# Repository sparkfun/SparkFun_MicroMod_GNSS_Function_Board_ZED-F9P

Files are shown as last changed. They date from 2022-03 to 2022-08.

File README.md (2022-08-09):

SparkFun MicroMod GNSS Function Board - ZED-F9P
========================================

SparkFun MicroMod GNSS Function Board - ZED-F9P (https://www.sparkfun.com/products/19663)

[*SparkFun MicroMod GNSS Function Board - ZED-F9P (GPS-19663)*](https://www.sparkfun.com/products/19663)

The SparkFun MicroMod GNSS Function Board - ZED-F9P provides high precision GNSS capabilities for MicroMod projects using Main Board/Function Board assemblies. The ZED-F9P module from u-blox is capable of up to 10mm 3-dimensional accuracy though the module requires a clear view of the sky as well as correction data from an RTCM source to achieve this level of precision. The ZED-F9P can act as a base station as well so you can use it with a second Function Board (or another SparkFun ZED-F9P product) together to achieve millimeter positional accuracy.

Repository Contents
-------------------

* **/Documentation** - Data sheets, additional product information
* **/Firmware** - Example code 
* **/Hardware** - Eagle design files (.brd, .sch)
* **/Libraries** - Libraries for use with the <PRODUCT NAME>
* **/Production** - Production panel files (.brd)
* **/Software** - Related software for the <PRODUCT NAME>

Documentation
--------------
* **[SparkFun u-blox GNSS Arduino Library](https://github.com/sparkfun/SparkFun_u-blox_GNSS_Arduino_Library)** - u-blox GNSS Arduino library for SparkFun u-blox products.
* **[Hookup Guide](https://learn.sparkfun.com/tutorials/micromod-gnss-function-board---zed-f9p-hookup-guide)** - Basic hookup guide for the MicroMod GNSS Function Board - ZED-F9P.

Product Versions
----------------
* [GPS-19663](https://www.sparkfun.com/products/19663)- MicroMod GNSS Function Board - ZED-F9P Initial Release

Issues
------------
See the [issue template](.github/ISSUE_TEMPLATE/) folder for more information on how to raise issues for bugs and new features.

License Information
-------------------

This product is _**open source**_! 

Please review the LICENSE.md file for license information. 

If you have any questions or concerns on licensing, please contact technical support on our [SparkFun forums](https://forum.sparkfun.com/viewforum.php?f=152).

Distributed as-is; no warranty is given.

- Your friends at SparkFun.

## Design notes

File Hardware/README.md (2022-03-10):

SparkFun <PRODUCT NAME> Design Files
=====================================

The .sch and .brd files hare are Eagle CAD schematic and PCB design files from SparkFun Electronics.
A freeware version of Autodesk Eagle can be found [here](https://www.autodesk.com/products/eagle/free-download).

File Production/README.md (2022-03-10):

SparkFun <PRODUCT NAME> Production Files
=========================================

These are the production files SparkFun uses for printing PCBs.

License Information
-------------------
This product is open source! 

The hardware is released under [Creative Commons ShareAlike 4.0 International](https://creativecommons.org/licenses/by-sa/4.0/).

Please use, reuse, and modify these files as you see fit. Please maintain attribution to SparkFun Electronics and release anything derivative under the same license.

Distributed as-is; no warranty is given.

- Your friends at SparkFun.

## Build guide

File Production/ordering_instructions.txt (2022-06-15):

panel size, 128x137mm
PCB thickness, 0.8mm
number of layers, 4
bevel, Gold Fingers + 45° Finger Chamfered
soldermask color, Red
silkscreen color, White
oz copper, 1oz
finish, ENIG
stencils, none
pcs per panel, 6
min trace width, 0.1100mm / 0.0043in
min drill size, 0.3000mm / 0.0118in
filename to layer stackup 1/2/3/4: GTL, GL2, GL3, GBL

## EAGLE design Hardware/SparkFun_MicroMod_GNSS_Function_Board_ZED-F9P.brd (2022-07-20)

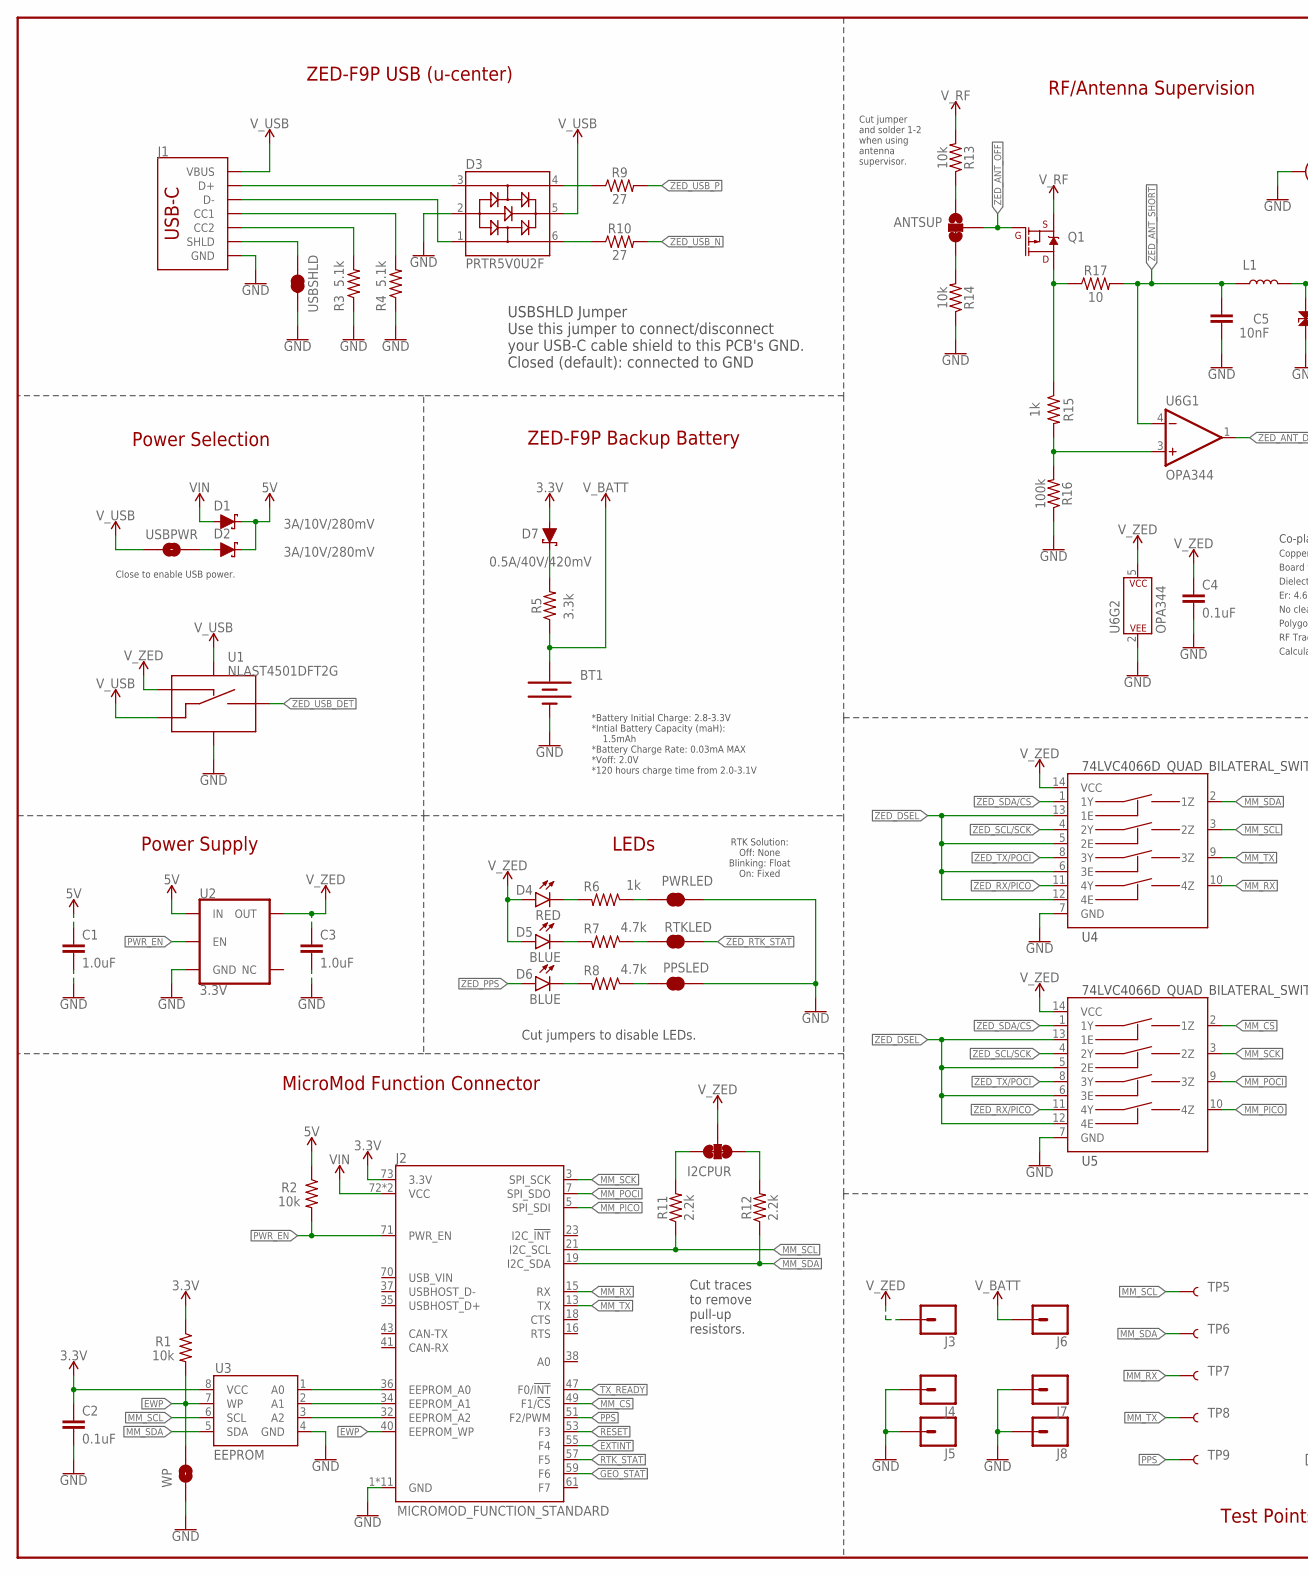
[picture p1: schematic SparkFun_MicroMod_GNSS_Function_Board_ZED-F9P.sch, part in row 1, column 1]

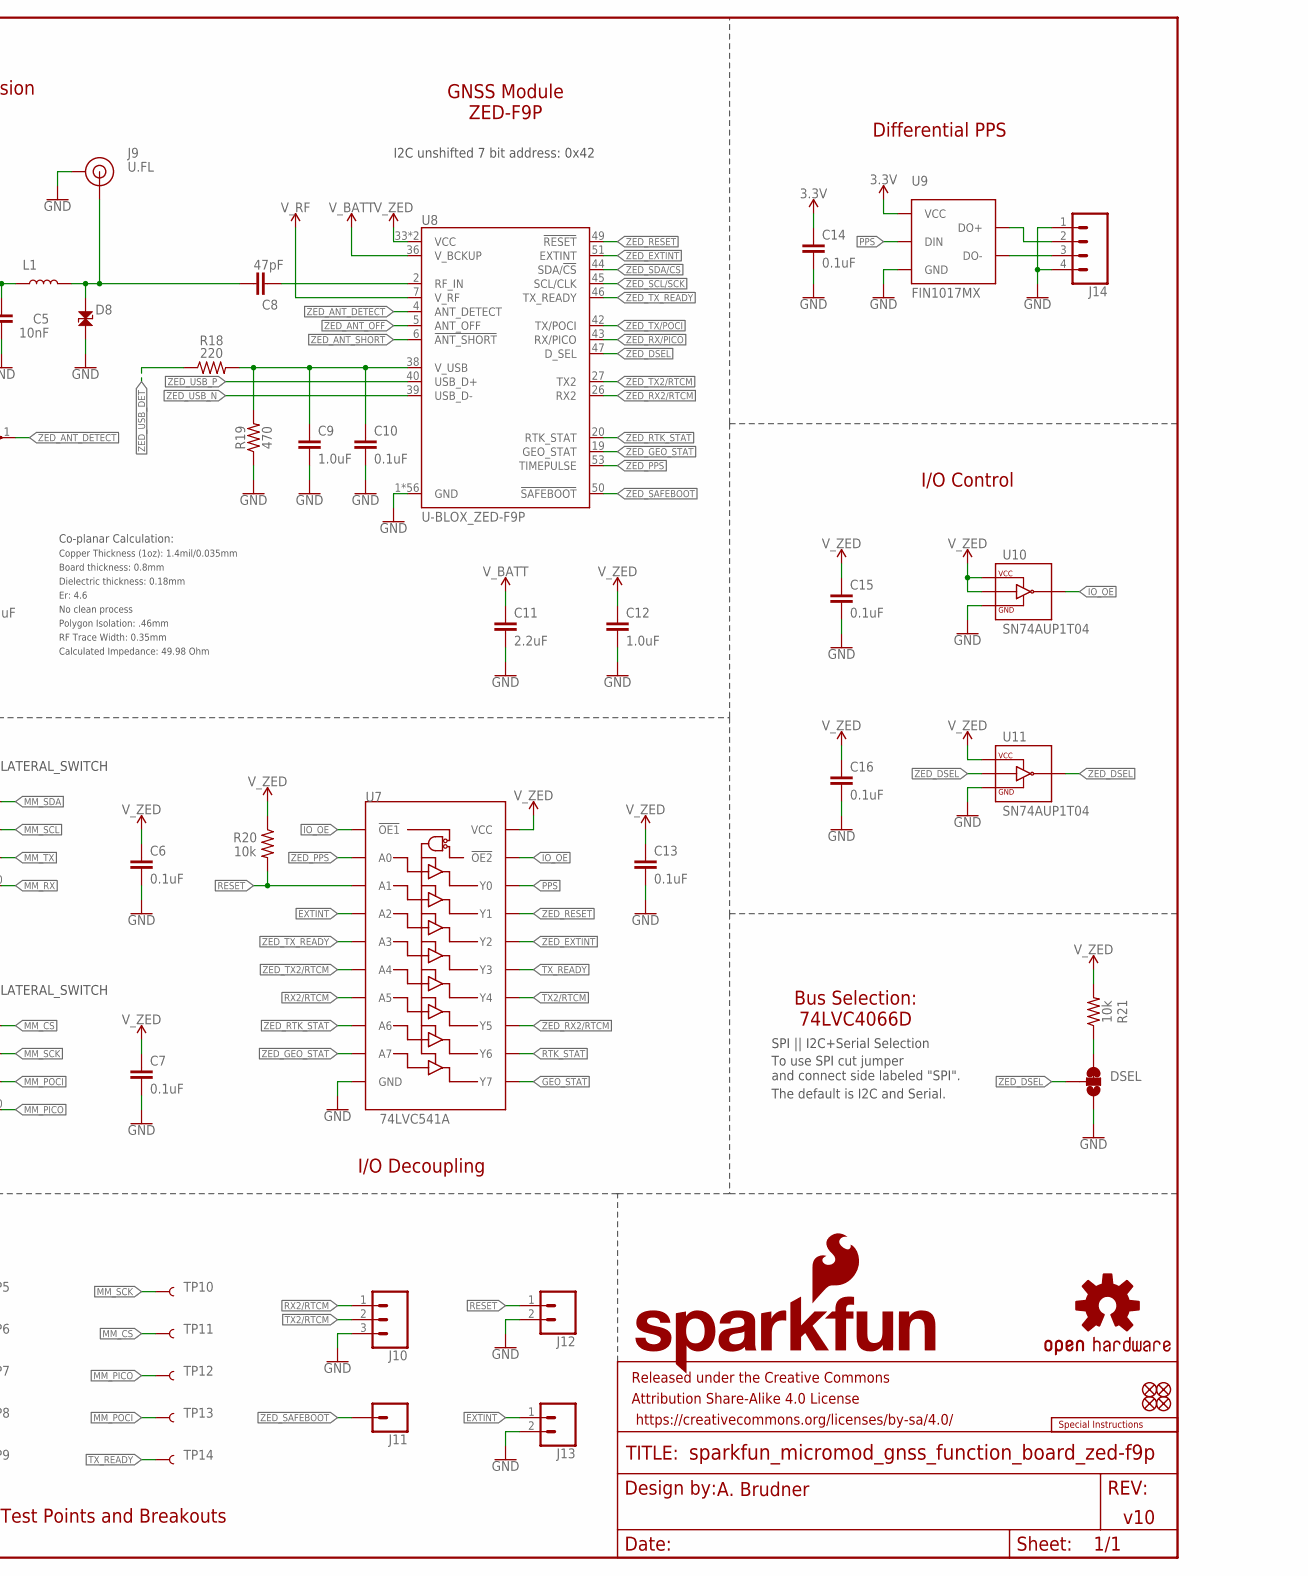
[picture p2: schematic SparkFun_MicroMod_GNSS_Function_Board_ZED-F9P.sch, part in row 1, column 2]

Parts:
ANTSUP: JUMPER-SMT_3_1-NC_TRACE_SILK; SMT-JUMPER_3_1-NC_TRACE_SILK
BT1: RELOWABLE_BATTERY_MS421R; MS421R_IV03E
C1, C3, C9, C12: 1.0uF; 0402-TIGHT
C2, C4, C6, C7, C10, C13, C14, C15, C16: 0.1uF; 0402-TIGHT
C5: 10nF; 0402-TIGHT
C8: 47pF; 0402-TIGHT
C11: 2.2uF; 0402-TIGHT
D1, D2: 3A/10V/280mV; SOD-323
D3: PRTR5V0U2F; SOT886
D4: RED; LED-0603
D5, D6: BLUE; LED-0603
D7: 0.5A/40V/420mV; SOD-323
D8: PESD0402-0402T; 0402-TIGHT
DSEL: JUMPER-SMT_3_1-NC_TRACE_SILK; SMT-JUMPER_3_1-NC_TRACE_SILK
FD1, FD2, FD3, FD4: FIDUCIALUFIDUCIAL; FIDUCIAL-MICRO
FRAME1: FRAME-LEDGER; CREATIVE_COMMONS
I2CPUR: JUMPER-SMT_3_2-NC_TRACE_SILK; SMT-JUMPER_3_2-NC_TRACE_SILK
J1: USB Female Type C Connector; USB-C-16P-4LAYER-ISOLATED
J2: MICROMOD_FUNCTION_STANDARD; M.2-CARD-E-22_FUNCTION_STANDARD
J3, J4, J5, J7, J8, J11: CONN_01PTH_NO_SILK_YES_STOP; 1X01_NO_SILK
J6: CONN_01PTH_NO_SILK_SMALL; 1X01_SMALL
J9: U.FL
J10: 455-1750-1-ND; 1X03_NO_SILK
J12, J13: CONN_021X02_NO_SILK; 1X02_NO_SILK
J14: CONN_041X04_NO_SILK; 1X04_NO_SILK
L1: 150nH; 0402_MURATA
LOGO1: SFE_LOGO_NAME_FLAMEBLANK; BLANK
LOGO2: SPECIAL_INSTRUCTIONS-ORDERING; ORDERING_INSTRUCTIONS
LOGO3: OSHW-LOGOMINI; OSHW-LOGO-MINI
PPSLED: JUMPER-SMT_2_NC_TRACE_SILK; SMT-JUMPER_2_NC_TRACE_SILK
PWRLED: JUMPER-SMT_2_NC_TRACE_SILK; SMT-JUMPER_2_NC_TRACE_SILK
Q1: DMP21D0UT-7; SOT523
R1, R2, R13, R14, R20, R21: 10k; 0402-TIGHT
R3, R4: 5.1k; 0402-TIGHT
R5: 3.3K; 0402-TIGHT
R6, R15: 1k; 0402-TIGHT
R7, R8: 4.7k; 0402-TIGHT
R9, R10: 27; 0402-TIGHT
R11, R12: 2.2k; 0402-TIGHT
R16: 100k; 0402-TIGHT
R17: 10; 0603
R18: 220; 0402-TIGHT
R19: 470; 0402-TIGHT
RTKLED: JUMPER-SMT_2_NC_TRACE_SILK; SMT-JUMPER_2_NC_TRACE_SILK
TP5, TP6, TP7, TP8, TP9, TP10, TP11, TP12, TP13, TP14: TEST-POINT3; PAD.03X.03
U1: NLAST4501DFT2G; SOT353
U2: 3.3V; SOT23-5
U3: EEPROM; SO08
U4, U5: 74LVC4066D_QUAD_BILATERAL_SWITCH; SO14
U6: OPA344; SOT23-5
U7: 74LVC541A; DHVQFN20
U8: U-BLOX_ZED-F9P; ZED-F9P
U9: FIN1017MX; SO08
U10, U11: SN74AUP1T04; SC-70-5_DCK
USBPWR: JUMPER-SMT_2_NO_SILK; SMT-JUMPER_2_NO_SILK
USBSHLD: JUMPER-SMT_2_NC_TRACE_SILK; SMT-JUMPER_2_NC_TRACE_SILK
WP: JUMPER-SMT_2_NO_SILK; SMT-JUMPER_2_NO_SILK

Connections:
3.3V: C2.1, C14.1, D7.A, J2.73 (3.3V), R1.1, U3.8 (VCC), U9.1 (VCC)
5V: C1.1, D1.C, D2.C, R2.1, U2.1 (IN)
!RESET!: J2.53 (F3), J12.1, R20.2, U7.3 (A1)
!ZED_DSEL!: U5.5 (2E), U5.6 (3E), U5.12 (4E), U5.13 (1E), U11.4 (Y)
A0: J2.36 (EEPROM_A0), U3.1 (A0)
A1: J2.34 (EEPROM_A1), U3.2 (A1)
A2: J2.32 (EEPROM_A2), U3.3 (A2)
EWP: J2.40 (EEPROM_WP), R1.2, U3.7 (WP), WP.2
EXTINT: J2.55 (F4), J13.1, U7.4 (A2)
GEO_STAT: J2.59 (F6), U7.11 (Y7)
GND: BT1.-, C1.2, C2.2, C3.2, C4.2, C5.2, C6.2, C7.2, C9.2, C10.2, C11.2, C12.2, C13.2, C14.2, C15.2, C16.2, D3.2, D8.2, DSEL.1, J1.GND, J1.GND2 (GND), J2.1 (GND), J2.33 (GND), J2.39 (GND), J2.45 (GND), J2.75 (GND), J2.GND1 (GND), J2.GND2 (GND), J2.GND3 (GND), J2.GND4 (GND), J2.GND5 (GND), J2.GND6 (GND), J4.1, J5.1, J7.1, J8.1, J9.1 (GND), J9.2 (GND), J10.3, J12.2, J13.2, J14.1, J14.4, PPSLED.1, PWRLED.2, R3.1, R4.1, R14.1, R16.1, R19.1, U1.3 (GND), U2.2 (GND), U3.4 (GND), U4.7 (GND), U5.7 (GND), U6.2 (P$V-), U7.10 (GND), U7.EPAD (GND), U8.1 (GND), U8.3 (GND), U8.12 (GND), U8.14 (GND), U8.32 (GND), U8.37 (GND), U8.41 (GND), U8.48 (GND), U8.55 (GND), U8.56 (GND), U8.57 (GND), U8.58 (GND), U8.59 (GND), U8.60 (GND), U8.61 (GND), U8.62 (GND), U8.63 (GND), U8.64 (GND), U8.65 (GND), U8.66 (GND), U8.67 (GND), U8.68 (GND), U8.69 (GND), U8.70 (GND), U8.71 (GND), U8.72 (GND), U8.73 (GND), U8.74 (GND), U8.75 (GND), U8.76 (GND), U8.77 (GND), U8.78 (GND), U8.79 (GND), U8.80 (GND), U8.81 (GND), U8.82 (GND), U8.83 (GND), U8.84 (GND), U8.85 (GND), U8.86 (GND), U8.87 (GND), U8.88 (GND), U8.89 (GND), U8.90 (GND), U8.91 (GND), U8.92 (GND), U8.93 (GND), U8.94 (GND), U8.95 (GND), U8.96 (GND), U8.97 (GND), U8.98 (GND), U8.99 (GND), U8.100 (GND), U8.101 (GND), U8.102 (GND), U9.4 (GND), U10.3 (GND), U11.3 (GND), USBSHLD.2, WP.1
IO_!OE!: U7.1 (!OE1!), U7.19 (!OE2!), U10.4 (Y)
MM_!CS!: J2.49 (F1/!CS!), TP11.1, U5.2 (1Z)
MM_PICO: J2.5 (SPI_SDI), TP12.1, U5.10 (4Z)
MM_POCI: J2.7 (SPI_SDO), TP13.1, U5.9 (3Z)
MM_RX: J2.15 (RX), TP7.1, U4.10 (4Z)
MM_SCK: J2.3 (SPI_SCK), TP10.1, U5.3 (2Z)
MM_SCL: J2.21 (I2C_SCL), R11.1, TP5.1, U3.6 (SCL), U4.3 (2Z)
MM_SDA: J2.19 (I2C_SDA), R12.1, TP6.1, U3.5 (SDA), U4.2 (1Z)
MM_TX: J2.13 (TX), TP8.1, U4.9 (3Z)
unnamed: ANTSUP.1, R13.1
unnamed: ANTSUP.3, R14.2
unnamed: J1.B5 (CC2), R3.2
unnamed: J1.A5 (CC1), R4.2
unnamed: DSEL.3, R21.1
unnamed: I2CPUR.3, R11.2
unnamed: C8.1, D8.1, J9.FEED (SIGNAL), L1.2
unnamed: R7.1, RTKLED.2
unnamed: I2CPUR.1, R12.2
unnamed: Q1.1 (D), R15.1, R17.1
unnamed: C9.1, C10.1, R18.2, R19.2, U8.38 (V_USB)
unnamed: D2.A, USBPWR.2
unnamed: PWRLED.1, R6.1
unnamed: PPSLED.2, R8.1
unnamed: D6.C, R8.2
unnamed: D5.C, R7.2
unnamed: D4.C, R6.2
unnamed: D7.C, R5.2
unnamed: R15.2, R16.2, U6.3 (+IN)
PPS: J2.51 (F2/PWM), TP9.1, U7.18 (Y0), U9.2 (DIN)
PPS_DIFF_N: J14.3, U9.8 (DO-)
PPS_DIFF_P: J14.2, U9.7 (DO+)
PWR_EN: J2.71 (PWR_EN), R2.2, U2.3 (EN)
RF_IN: C8.2, U8.2 (RF_IN)
RTK_STAT: J2.57 (F5), U7.12 (Y6)
RX2/RTCM: J10.1, U7.7 (A5)
SHLD: J1.SHLD1 (SHLD), J1.SHLD2 (SHLD), J1.SHLD3 (SHLD), J1.SHLD4 (SHLD), J1.SHLD5 (SHLD), J1.SHLD6 (SHLD), J1.SHLD7 (SHLD), J1.SHLD8 (SHLD), USBSHLD.1
TX2/RTCM: J10.2, U7.14 (Y4)
TX_READY: J2.47 (F0/!INT!), TP14.1, U7.15 (Y3)
USBC_N: D3.1, J1.A7 (D-), J1.B7 (D-)
USBC_P: D3.3, J1.A6 (D+), J1.B6 (D+)
USB_N: D3.6, R10.1
USB_P: D3.4, R9.1
VIN: D1.A, J2.72 (VCC), J2.74 (VCC)
V_BATT: BT1.+, C11.1, J6.P$1, R5.1, U8.36 (V_BCKUP)
V_RF: Q1.2 (S), R13.2, U8.7 (V_RF)
V_USB: D3.5, J1.VBUS1 (VBUS), J1.VBUS2 (VBUS), U1.1 (COM), U1.5 (VCC), USBPWR.1
V_ZED: C3.1, C4.1, C6.1, C7.1, C12.1, C13.1, C15.1, C16.1, D4.A, D5.A, I2CPUR.2, J3.1, R20.1, R21.2, U1.4 (EN), U2.5 (OUT), U4.14 (VCC), U5.14 (VCC), U6.5 (P$V+), U7.20 (VCC), U8.33 (VCC), U8.34 (VCC), U10.2 (A), U10.5 (VCC), U11.5 (VCC)
ZED_!RESET!: U7.17 (Y1), U8.49 (!RESET!)
ZED_!SAFEBOOT!: J11.1, U8.50 (!SAFEBOOT!)
ZED_ANT_!SHORT!: C5.1, L1.1, R17.2, U6.4 (-IN), U8.6 (!ANT_SHORT!)
ZED_ANT_DETECT: U6.1 (OUT), U8.4 (ANT_DETECT)
ZED_ANT_OFF: ANTSUP.2, Q1.3 (G), U8.5 (ANT_OFF)
ZED_DSEL: DSEL.2, U4.5 (2E), U4.6 (3E), U4.12 (4E), U4.13 (1E), U8.47 (D_SEL), U11.2 (A)
ZED_EXTINT: U7.16 (Y2), U8.51 (EXTINT)
ZED_GEO_STAT: U7.9 (A7), U8.19 (GEO_STAT)
ZED_PPS: D6.A, U7.2 (A0), U8.53 (TIMEPULSE)
ZED_RTK_STAT: RTKLED.1, U7.8 (A6), U8.20 (RTK_STAT)
ZED_RX2/RTCM: U7.13 (Y5), U8.26 (RX2)
ZED_RX/PICO: U4.11 (4Y), U5.11 (4Y), U8.43 (RX/PICO)
ZED_SCL/SCK: U4.4 (2Y), U5.4 (2Y), U8.45 (SCL/CLK)
ZED_SDA/!CS!: U4.1 (1Y), U5.1 (1Y), U8.44 (SDA/!CS!)
ZED_TX2/RTCM: U7.6 (A4), U8.27 (TX2)
ZED_TX/POCI: U4.8 (3Y), U5.8 (3Y), U8.42 (TX/POCI)
ZED_TX_READY: U7.5 (A3), U8.46 (TX_READY)
ZED_USB_DET: R18.1, U1.2 (NO)
ZED_USB_N: R10.2, U8.39 (USB_D-)
ZED_USB_P: R9.2, U8.40 (USB_D+)

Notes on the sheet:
MicroMod Function Connector
A. Brudner
v10
ZED-F9P USB (u-center)
ZED-F9P Backup Battery
LEDs
Cut jumpers to disable LEDs.
I/O Decoupling
I/O Control
Power Supply
Power Selection
Board thickness: 0.8mm
Er: 4.6
Copper Thickness (1oz): 1.4mil/0.035mm
RF Trace Width: 0.35mm
Polygon Isolation: .46mm
No clean process
Dielectric thickness: 0.18mm
Co-planar Calculation:
Calculated Impedance: 49.98 Ohm
*Battery Initial Charge: 2.8-3.3V *Intial Battery Capacity (maH): 1.5mAh *Battery Charge Rate: 0.03mA MAX *Voff: 2.0V *120 hours charge time from 2.0-3.1V
GNSS Module ZED-F9P
RF/Antenna Supervision
Cut jumper and solder 1-2 when using antenna supervisor.
Differential PPS
Bus Selection: 74LVC4066D
To use SPI cut jumper and connect side labeled "SPI".
SPI || I2C+Serial Selection
The default is I2C and Serial.
Close to enable USB power.
Test Points and Breakouts
I2C unshifted 7 bit address: 0x42
Cut traces to remove pull-up resistors.
RTK Solution: Off: None Blinking: Float On: Fixed
USBSHLD Jumper Use this jumper to connect/disconnect your USB-C cable shield to this PCB's GND. Closed (default): connected to GND

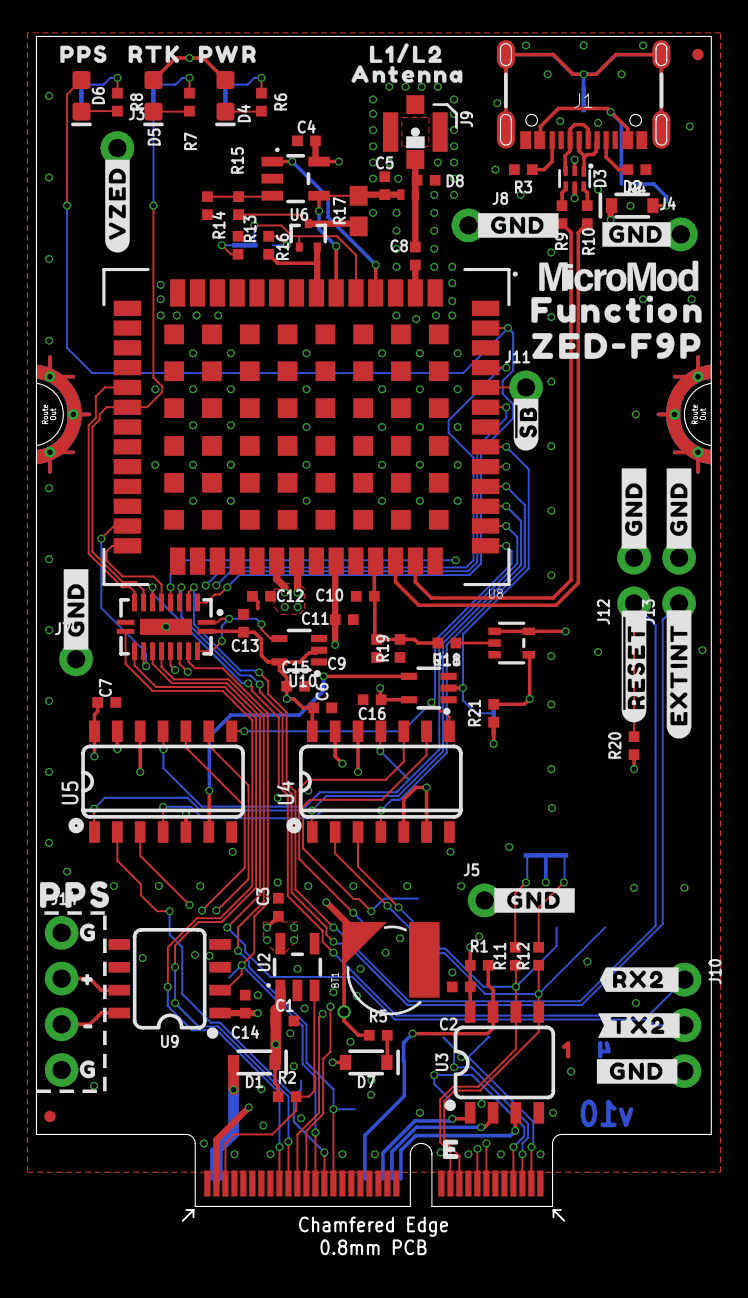
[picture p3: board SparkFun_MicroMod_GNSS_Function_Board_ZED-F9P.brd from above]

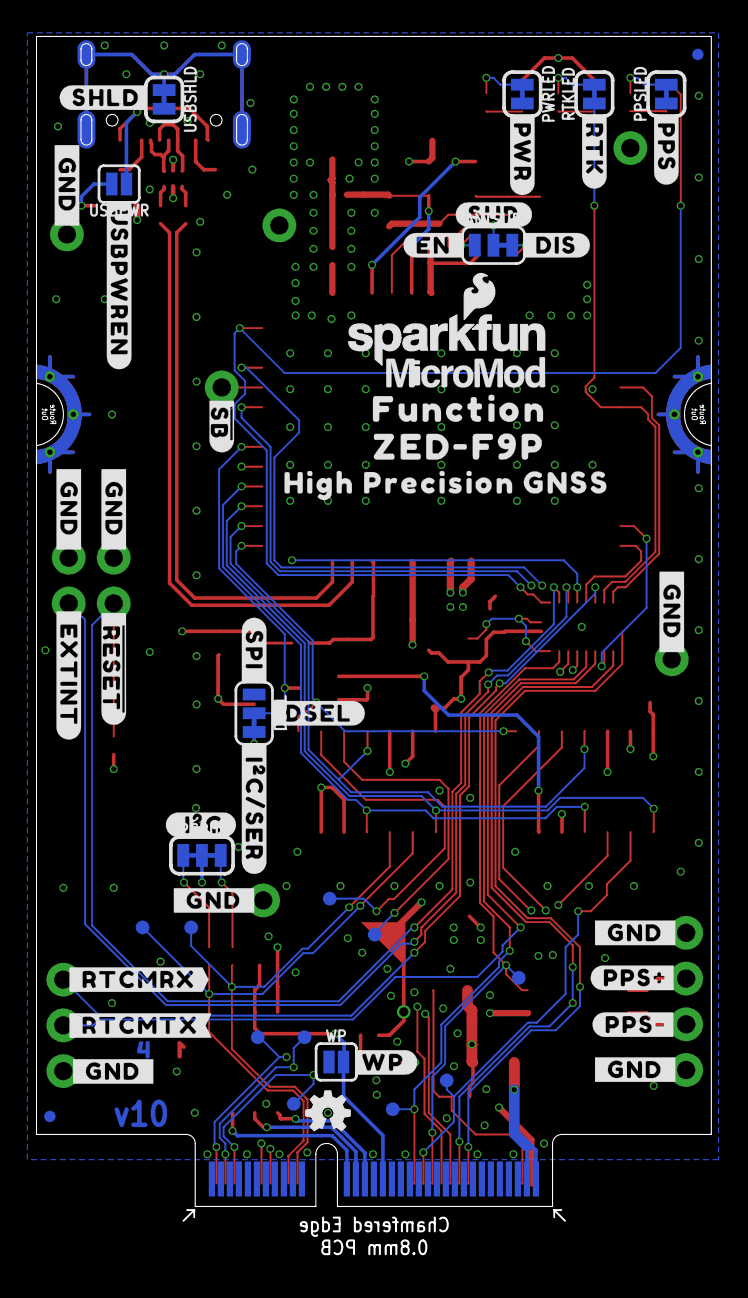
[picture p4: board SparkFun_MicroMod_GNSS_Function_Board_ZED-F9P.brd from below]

Board: 4 copper layers, 37.5 x 65.8 mm, 164 parts (56 on the bottom side), 78 nets.

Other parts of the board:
LOGO4: SFE_LOGO_NAME_FLAME.1_INCH; SFE_LOGO_NAME_FLAME_.1
U$1: 40
U$2: #_RTCMTX#0
U$3: #TX2_#0
U$5, U$6, U$7, U$9, U$10, U$11, U$18, U$19, U$21, U$22, U$25, U$33, U$38, U$39: #_GND_#0
U$12: #_RTCMRX#0
U$13: #RX2_#0
U$14: ##RESET_##0
U$15: #_#RESET##0
U$16: #_EXTINT#0
U$17: #EXTINT_#0
U$23: #_I�C#SER#0
U$24: #SPI_#0
U$26, U$27: FUNCTION0
U$28: #_I�C#0
U$29: #_DSEL#0
U$30: #SUP#0
U$31: #RTK#0
U$32: #PWR#0
U$34: 10
U$35: 211
U$36: 3212
U$37, U$63: MICROMOD_LOGO_.35
U$40: PPS3
U$44: #PPS##2252
U$45: #PPS##2253
U$46, U$47: G2
U$48: #3
U$49: #4
U$50: #PPS#2254
U$51: PPS0
U$52: RTK0
U$54: #WP#0
U$62: #USBPWREN#10
U$64: #SHLD#12
U$68: #VZED#0
U$72: PWR0
U$73: #_DIS#0
U$74: #EN_#0
U$76: ##SB##9
U$80: ##SB##0
U$82: #GND#0
U$85: L1#L20
U$87: ANTENNA0
U$104: SFE_LOGO_FLAME_STOP_.1
U$106: HIGH_PRECISION_GNSS26
U$112, U$114: ZED#F9P0

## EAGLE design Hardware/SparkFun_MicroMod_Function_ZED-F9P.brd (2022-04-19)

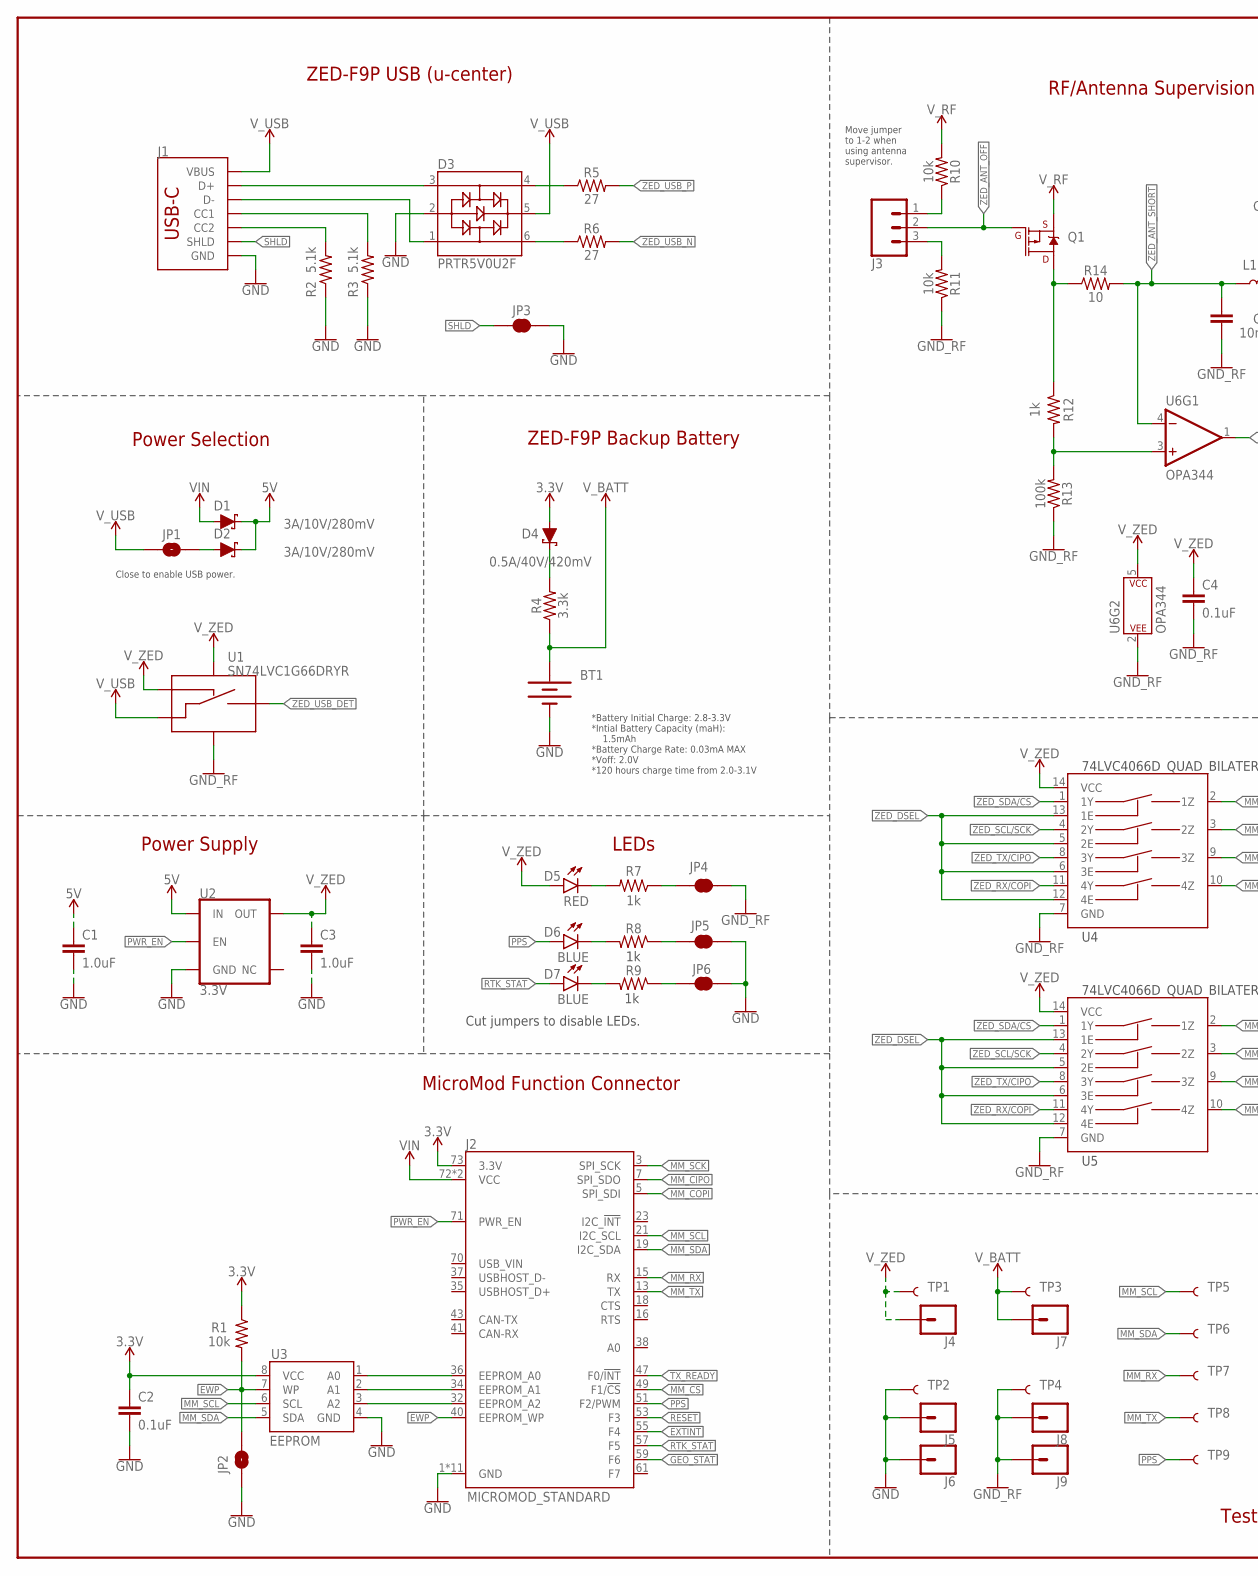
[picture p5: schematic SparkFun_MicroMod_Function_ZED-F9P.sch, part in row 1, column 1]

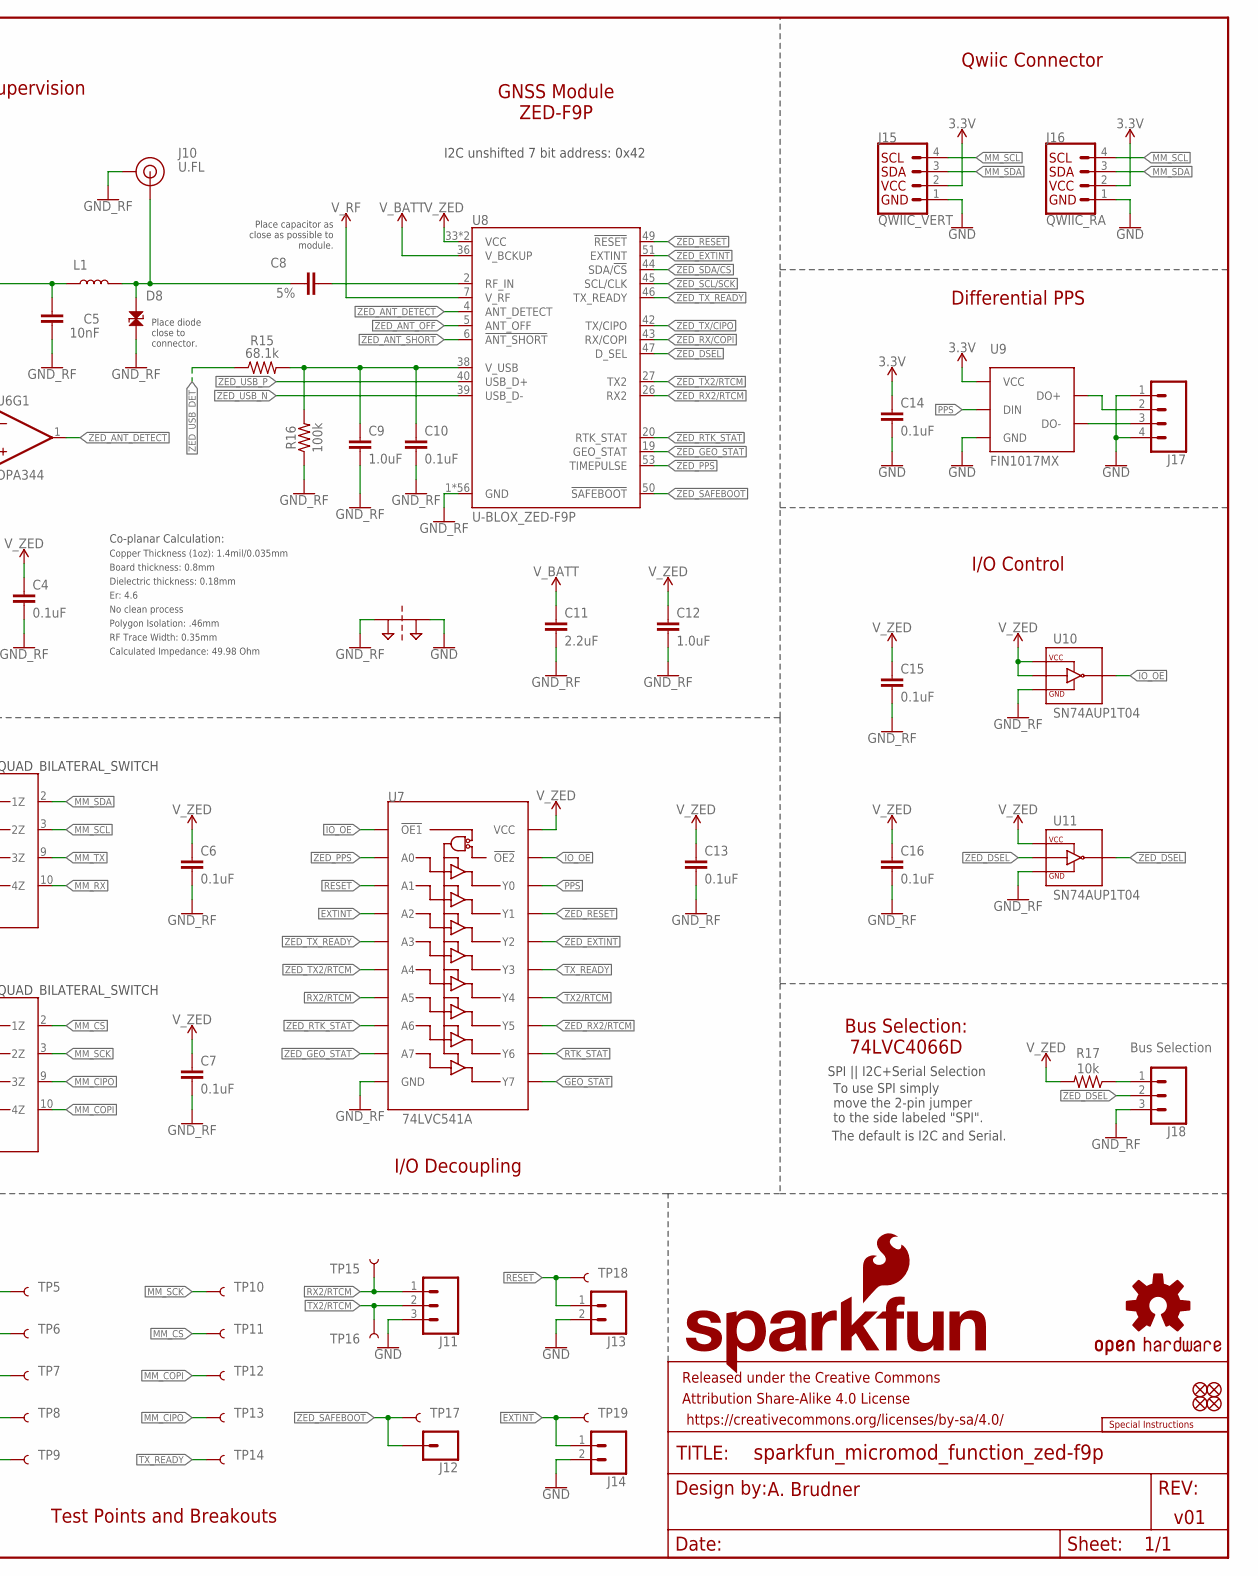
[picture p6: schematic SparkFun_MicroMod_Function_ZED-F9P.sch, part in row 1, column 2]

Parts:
BT1: RELOWABLE_BATTERY_MS421R; MS421R_IV03E
C1, C3, C9, C12: 1.0uF; 0402-TIGHT
C2, C4, C6, C7, C10, C13, C14, C15, C16: 0.1uF; 0402-TIGHT
C5: 10nF; 0402-TIGHT
C8: 47pF; 0402-TIGHT
C11: 2.2uF; 0402-TIGHT
D1, D2: 3A/10V/280mV; SOD-323
D3: PRTR5V0U2F; SOT886
D4: 0.5A/40V/420mV; SOD-323
D5: RED; LED-0603
D6, D7: BLUE; LED-0603
D8: PESD0402-0402T; 0402-TIGHT
FD1, FD2, FD3, FD4: FIDUCIALUFIDUCIAL; FIDUCIAL-MICRO
FRAME1: FRAME-LEDGER; CREATIVE_COMMONS
J1: USB Female Type C Connector; USB-C-16P-4LAYER-ISOLATED
J2: MICROMOD_STANDARD; M.2-CARD-E-22_FUNCTION_STANDARD
J3, J18: Bus Selection; 1X03_LOCK
J4, J5, J6, J8, J9, J12: CONN_01; 1X01
J7: CONN_01PTH_NO_SILK_SMALL; 1X01_SMALL
J10: U.FL
J11: 455-1750-1-ND; 1X03
J13, J14: CONN_02; 1X02
J15: QWIIC_VERT; JST04_1MM_VERT
J16: QWIIC_RA; JST04_1MM_RA
J17: CONN_04PTH; 1X04
JP1, JP2: JUMPER-SMT_2_NO_SILK; SMT-JUMPER_2_NO_SILK
JP3, JP4, JP5, JP6: JUMPER-SMT_2_NC_TRACE_SILK; SMT-JUMPER_2_NC_TRACE_SILK
L1: 150nH; 0402_MURATA
LOGO1: SFE_LOGO_NAME_FLAMEBLANK; BLANK
LOGO2: SPECIAL_INSTRUCTIONS-ORDERING; ORDERING_INSTRUCTIONS
LOGO3: OSHW-LOGOMINI; OSHW-LOGO-MINI
Q1: DMP21D0UT-7; SOT523
R1, R10, R11, R17: 10k; 0603
R2, R3: 5.1k; 0603
R4: 3.3k; 0603
R5, R6: 27; 0402-TIGHT
R7, R8, R9, R12: 1k; 0603
R13, R16: 100k; 0603
R14: 10; 0603
R15: 68.1k; 0603
SUPPLYTIE1: 2PT_GND_TIE
TP1, TP2, TP3, TP4, TP5, TP6, TP7, TP8, TP9, TP10, TP11, TP12, TP13, TP14, TP15, TP16, TP17, TP18, TP19: TEST-POINT3; PAD.03X.03
U1: SN74LVC1G66DRYR; USON_DRY0006A
U2: 3.3V; SOT23-5
U3: EEPROM; SO08
U4, U5: 74LVC4066D_QUAD_BILATERAL_SWITCH; SO14
U6: OPA344; SOT23-5
U7: 74LVC541A; DHVQFN20
U8: U-BLOX_ZED-F9P; ZED-F9P
U9: FIN1017MX; SO08
U10, U11: SN74AUP1T04; SC-70-5_DCK

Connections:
3.3V: C2.1, C14.1, D4.A, J2.73 (3.3V), J15.2, J16.2, R1.1, U3.8 (VCC), U9.1 (VCC)
5V: C1.1, D1.C, D2.C, U2.1 (IN)
!RESET!: J2.53 (F3), J13.1, TP18.1, U7.P$3 (A1)
!ZED_DSEL!: U5.5 (2E), U5.6 (3E), U5.12 (4E), U5.13 (1E), U11.P$4 (Y)
A0: J2.36 (EEPROM_A0), U3.1 (A0)
A1: J2.34 (EEPROM_A1), U3.2 (A1)
A2: J2.32 (EEPROM_A2), U3.3 (A2)
EWP: J2.40 (EEPROM_WP), JP2.2, R1.2, U3.7 (WP)
EXTINT: J2.55 (F4), J14.1, TP19.1, U7.P$4 (A2)
GEO_STAT: J2.59 (F6), U7.P$11 (Y7)
GND: BT1.-, C1.2, C2.2, C3.2, C14.2, D3.2, J1.GND, J1.GND2 (GND), J2.1 (GND), J2.33 (GND), J2.39 (GND), J2.45 (GND), J2.75 (GND), J2.GND1 (GND), J2.GND2 (GND), J2.GND3 (GND), J2.GND4 (GND), J2.GND5 (GND), J2.GND6 (GND), J5.1, J6.1, J11.3, J13.2, J14.2, J15.1, J16.1, J17.1, J17.4, JP2.1, JP3.2, JP5.1, JP6.1, R2.1, R3.1, SUPPLYTIE1.P$2, TP2.1, U2.2 (GND), U3.4 (GND), U9.4 (GND)
GND_RF: C4.2, C5.2, C6.2, C7.2, C9.2, C10.2, C11.2, C12.2, C13.2, C15.2, C16.2, D8.2, J8.1, J9.1, J10.1 (GND), J10.2 (GND), J18.3, JP4.2, R11.1, R13.1, R16.1, SUPPLYTIE1.P$1, TP4.1, U1.P$3 (VSS), U4.7 (GND), U5.7 (GND), U6.2 (P$V-), U7.EPAD (GND), U7.P$10 (GND), U8.1 (GND), U8.3 (GND), U8.12 (GND), U8.14 (GND), U8.32 (GND), U8.37 (GND), U8.41 (GND), U8.48 (GND), U8.55 (GND), U8.56 (GND), U8.57 (GND), U8.58 (GND), U8.59 (GND), U8.60 (GND), U8.61 (GND), U8.62 (GND), U8.63 (GND), U8.64 (GND), U8.65 (GND), U8.66 (GND), U8.67 (GND), U8.68 (GND), U8.69 (GND), U8.70 (GND), U8.71 (GND), U8.72 (GND), U8.73 (GND), U8.74 (GND), U8.75 (GND), U8.76 (GND), U8.77 (GND), U8.78 (GND), U8.79 (GND), U8.80 (GND), U8.81 (GND), U8.82 (GND), U8.83 (GND), U8.84 (GND), U8.85 (GND), U8.86 (GND), U8.87 (GND), U8.88 (GND), U8.89 (GND), U8.90 (GND), U8.91 (GND), U8.92 (GND), U8.93 (GND), U8.94 (GND), U8.95 (GND), U8.96 (GND), U8.97 (GND), U8.98 (GND), U8.99 (GND), U8.100 (GND), U8.101 (GND), U8.102 (GND), U10.P$3 (GND), U11.P$3 (GND)
IO_!OE!: U7.P$1 (!OE1!), U7.P$19 (!OE2!), U10.P$4 (Y)
MM_!CS!: J2.49 (F1/!CS!), TP11.1, U5.2 (1Z)
MM_CIPO: J2.7 (SPI_SDO), TP13.1, U5.9 (3Z)
MM_COPI: J2.5 (SPI_SDI), TP12.1, U5.10 (4Z)
MM_RX: J2.15 (RX), TP7.1, U4.10 (4Z)
MM_SCK: J2.3 (SPI_SCK), TP10.1, U5.3 (2Z)
MM_SCL: J2.21 (I2C_SCL), J15.4, J16.4, TP5.1, U3.6 (SCL), U4.3 (2Z)
MM_SDA: J2.19 (I2C_SDA), J15.3, J16.3, TP6.1, U3.5 (SDA), U4.2 (1Z)
MM_TX: J2.13 (TX), TP8.1, U4.9 (3Z)
unnamed: J1.B5 (CC2), R2.2
unnamed: J1.A5 (CC1), R3.2
unnamed: C8.1, D8.1, J10.FEED (SIGNAL), L1.P$2 (2)
unnamed: JP6.2, R9.1
unnamed: J18.1, R17.1
unnamed: J3.1, R10.1
unnamed: J3.3, R11.2
unnamed: Q1.P$1 (D), R12.1, R14.1
unnamed: C9.1, C10.1, R15.2, R16.2, U8.38 (V_USB)
unnamed: D2.A, JP1.2
unnamed: JP4.1, R7.1
unnamed: JP5.2, R8.1
unnamed: D6.C, R8.2
unnamed: D7.C, R9.2
unnamed: D5.C, R7.2
unnamed: D4.C, R4.2
unnamed: R12.2, R13.2, U6.3 (+IN)
PPS: D6.A, J2.51 (F2/PWM), TP9.1, U7.P$18 (Y0), U9.2 (DIN)
PPS_DIFF_N: J17.3, U9.8 (DO-)
PPS_DIFF_P: J17.2, U9.7 (DO+)
PWR_EN: J2.71 (PWR_EN), U2.3 (EN)
RF_IN: C8.2, U8.2 (RF_IN)
RTK_STAT: D7.A, J2.57 (F5), U7.P$12 (Y6)
RX2/RTCM: J11.1, TP15.1, U7.P$7 (A5)
SHLD: J1.SHLD1 (SHLD), J1.SHLD2 (SHLD), J1.SHLD3 (SHLD), J1.SHLD4 (SHLD), J1.SHLD5 (SHLD), J1.SHLD6 (SHLD), J1.SHLD7 (SHLD), J1.SHLD8 (SHLD), JP3.1
TX2/RTCM: J11.2, TP16.1, U7.P$14 (Y4)
TX_READY: J2.47 (F0/!INT!), TP14.1, U7.P$15 (Y3)
USBC_N: D3.1, J1.A7 (D-), J1.B7 (D-)
USBC_P: D3.3, J1.A6 (D+), J1.B6 (D+)
USB_N: D3.6, R6.1
USB_P: D3.4, R5.1
VIN: D1.A, J2.72 (VCC), J2.74 (VCC)
V_BATT: BT1.+, C11.1, J7.P$1, R4.1, TP3.1, U8.36 (V_BCKUP)
V_RF: Q1.P$2 (S), R10.2, U8.7 (V_RF)
V_USB: D3.5, J1.VBUS1 (VBUS), J1.VBUS2 (VBUS), JP1.1, U1.P$1 (A_IN)
V_ZED: C3.1, C4.1, C6.1, C7.1, C12.1, C13.1, C15.1, C16.1, D5.A, J4.1, R17.2, TP1.1, U1.P$4 (CTRL_IN), U1.P$6 (VCC), U2.5 (OUT), U4.14 (VCC), U5.14 (VCC), U6.5 (P$V+), U7.P$20 (VCC), U8.33 (VCC), U8.34 (VCC), U10.P$2 (A), U10.P$5 (VCC), U11.P$5 (VCC)
ZED_!RESET!: U7.P$17 (Y1), U8.49 (!RESET!)
ZED_!SAFEBOOT!: J12.1, TP17.1, U8.50 (!SAFEBOOT!)
ZED_ANT_!SHORT!: C5.1, L1.P$1 (1), R14.2, U6.4 (-IN), U8.6 (!ANT_SHORT!)
ZED_ANT_DETECT: U6.1 (OUT), U8.4 (ANT_DETECT)
ZED_ANT_OFF: J3.2, Q1.P$3 (G), U8.5 (ANT_OFF)
ZED_DSEL: J18.2, U4.5 (2E), U4.6 (3E), U4.12 (4E), U4.13 (1E), U8.47 (D_SEL), U11.P$2 (A)
ZED_EXTINT: U7.P$16 (Y2), U8.51 (EXTINT)
ZED_GEO_STAT: U7.P$9 (A7), U8.19 (GEO_STAT)
ZED_PPS: U7.P$2 (A0), U8.53 (TIMEPULSE)
ZED_RTK_STAT: U7.P$8 (A6), U8.20 (RTK_STAT)
ZED_RX2/RTCM: U7.P$13 (Y5), U8.26 (RX2)
ZED_RX/COPI: U4.11 (4Y), U5.11 (4Y), U8.43 (RX/COPI)
ZED_SCL/SCK: U4.4 (2Y), U5.4 (2Y), U8.45 (SCL/CLK)
ZED_SDA/!CS!: U4.1 (1Y), U5.1 (1Y), U8.44 (SDA/!CS!)
ZED_TX2/RTCM: U7.P$6 (A4), U8.27 (TX2)
ZED_TX/CIPO: U4.8 (3Y), U5.8 (3Y), U8.42 (TX/CIPO)
ZED_TX_READY: U7.P$5 (A3), U8.46 (TX_READY)
ZED_USB_DET: R15.1, U1.P$2 (A_OUT)
ZED_USB_N: R6.2, U8.39 (USB_D-)
ZED_USB_P: R5.2, U8.40 (USB_D+)

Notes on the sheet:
MicroMod Function Connector
A. Brudner
v01
ZED-F9P USB (u-center)
ZED-F9P Backup Battery
LEDs
Cut jumpers to disable LEDs.
Qwiic Connector
I/O Decoupling
I/O Control
Power Supply
Power Selection
Board thickness: 0.8mm
Er: 4.6
Copper Thickness (1oz): 1.4mil/0.035mm
RF Trace Width: 0.35mm
Polygon Isolation: .46mm
No clean process
Dielectric thickness: 0.18mm
Co-planar Calculation:
Calculated Impedance: 49.98 Ohm
*Battery Initial Charge: 2.8-3.3V *Intial Battery Capacity (maH): 1.5mAh *Battery Charge Rate: 0.03mA MAX *Voff: 2.0V *120 hours charge time from 2.0-3.1V
Place capacitor as close as possible to module.
GNSS Module ZED-F9P
RF/Antenna Supervision
Place diode close to connector.
Move jumper to 1-2 when using antenna supervisor.
Differential PPS
Bus Selection: 74LVC4066D
To use SPI simply move the 2-pin jumper to the side labeled "SPI".
SPI || I2C+Serial Selection
The default is I2C and Serial.
Close to enable USB power.
Test Points and Breakouts
I2C unshifted 7 bit address: 0x42

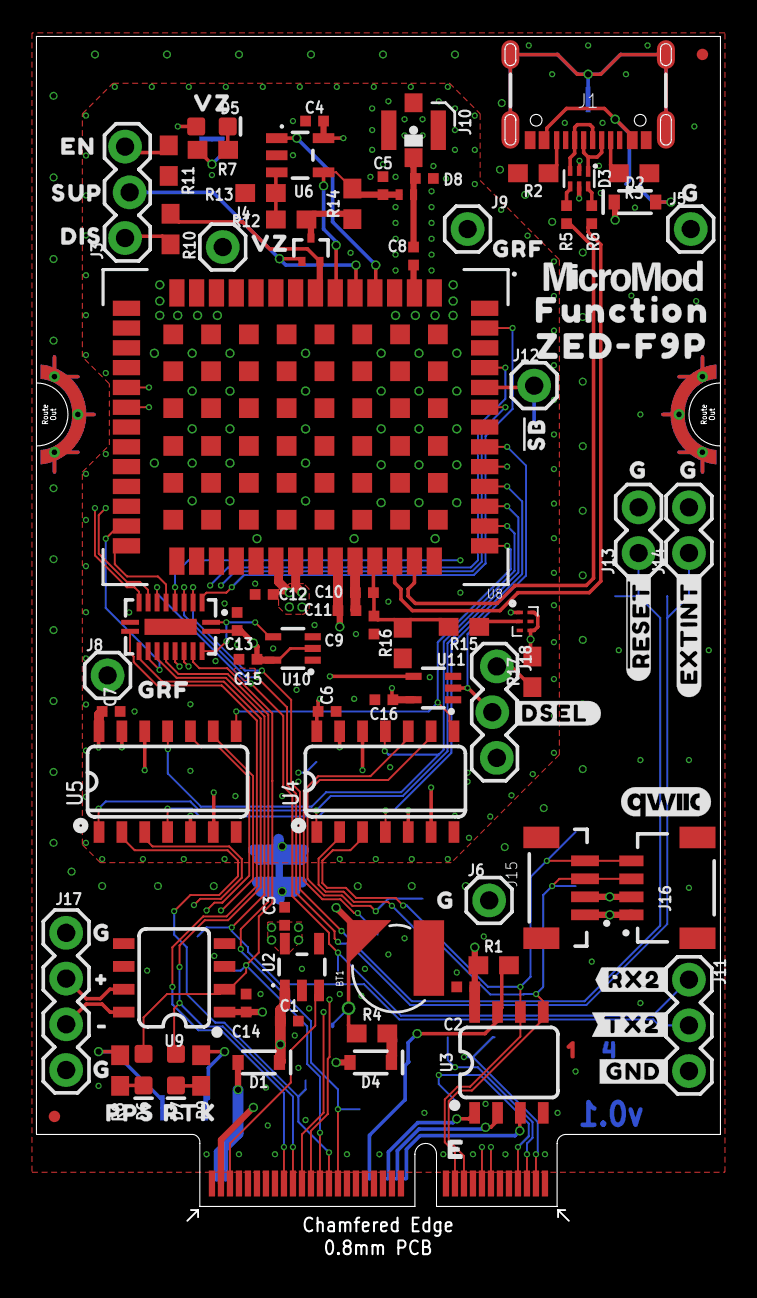
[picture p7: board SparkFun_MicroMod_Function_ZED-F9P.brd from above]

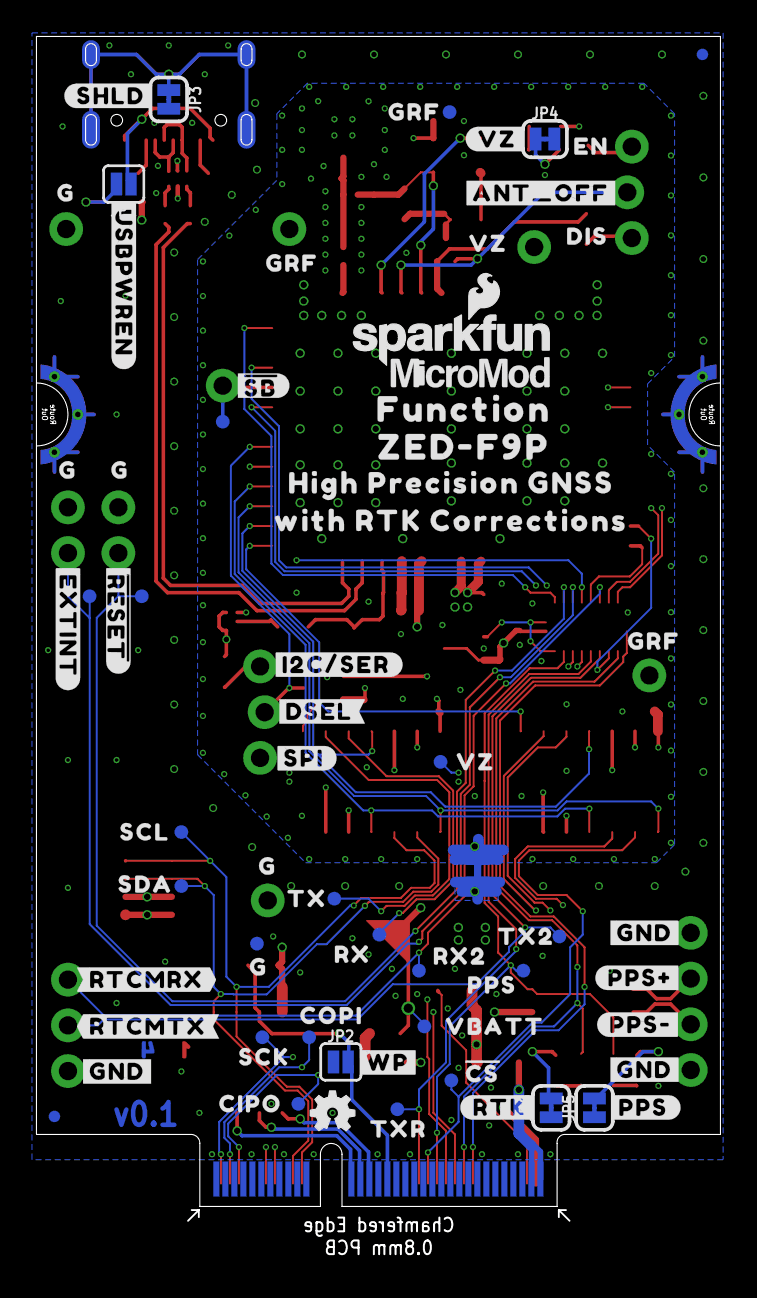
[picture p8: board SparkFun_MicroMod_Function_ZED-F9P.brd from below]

Board: 4 copper layers, 38.0 x 65.8 mm, 191 parts (80 on the bottom side), 77 nets.

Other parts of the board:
LOGO4: SFE_LOGO_NAME_FLAME.1_INCH; SFE_LOGO_NAME_FLAME_.1
U$26, U$27: FUNCTION0
U$34: 10
U$35: 211
U$36: 3212
U$37, U$63: MICROMOD_LOGO_.35
U$38: 43213
U$39: #RTCMTX#0
U$40: #RTCMRX#0
U$41, U$42, U$43, U$99: #GND#0
U$44: #PPS##2252
U$45: #PPS##2253
U$46, U$47, U$55, U$56, U$57, U$58, U$59, U$78, U$79, U$101, U$102: G2
U$48: #3
U$49: #4
U$50: #PPS#2254
U$51: PPS0
U$52: RTK0
U$53: #RTK#2255
U$54: #WP#8
U$60: #EXTINT#0
U$61: #EXTINT#2
U$62: #USBPWREN#10
U$64: #SHLD#12
U$65: ##RESET##3
U$66, U$67, U$69, U$96, U$100: GRF17
U$68: COPI2239
U$70: #SPI#30
U$71: VBATT18
U$72: VZ4
U$73, U$89, U$90: VZ19
U$74: #ANT_OFF#22
U$75: #VZ#5
U$76: ##SB##9
U$77: WITH_RTK_CORRECTIONS28
U$80: #SB#29
U$81: #DSEL#29
U$82: RX231
U$83: RX232
U$84: TX233
U$85: TX2234
U$86: PPS2235
U$87: SCL2236
U$88: SDA2237
U$91: CIPO2240
U$92: SCK2241
U$93: TXR2246
U$94: #CS#2245
U$95: #DSEL#31
U$97: #RX2#2249
U$98: #TX2#2249
U$103: #I2C#SER#30
U$104: SFE_LOGO_FLAME_STOP_.1
U$105: ##RESET##0
U$106: HIGH_PRECISION_GNSS26
U$107, U$110: EN32
U$108, U$109: DIS33
U$111: SUP35
U$112, U$114: ZED#F9P0
U$113: QWIIC_5MM

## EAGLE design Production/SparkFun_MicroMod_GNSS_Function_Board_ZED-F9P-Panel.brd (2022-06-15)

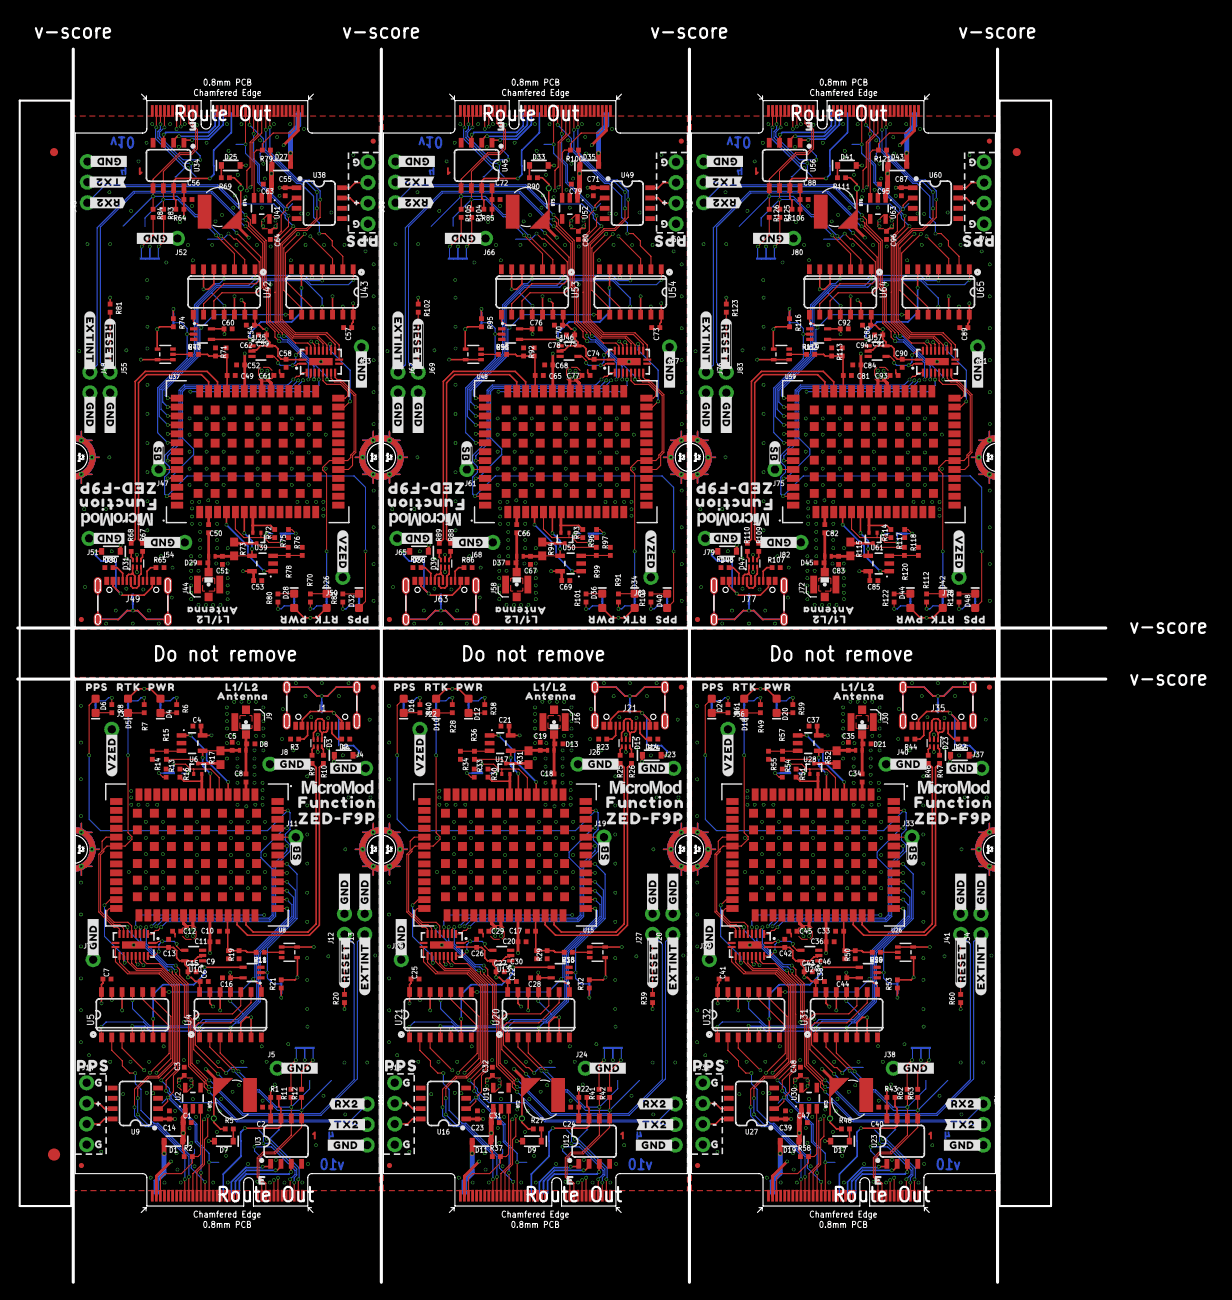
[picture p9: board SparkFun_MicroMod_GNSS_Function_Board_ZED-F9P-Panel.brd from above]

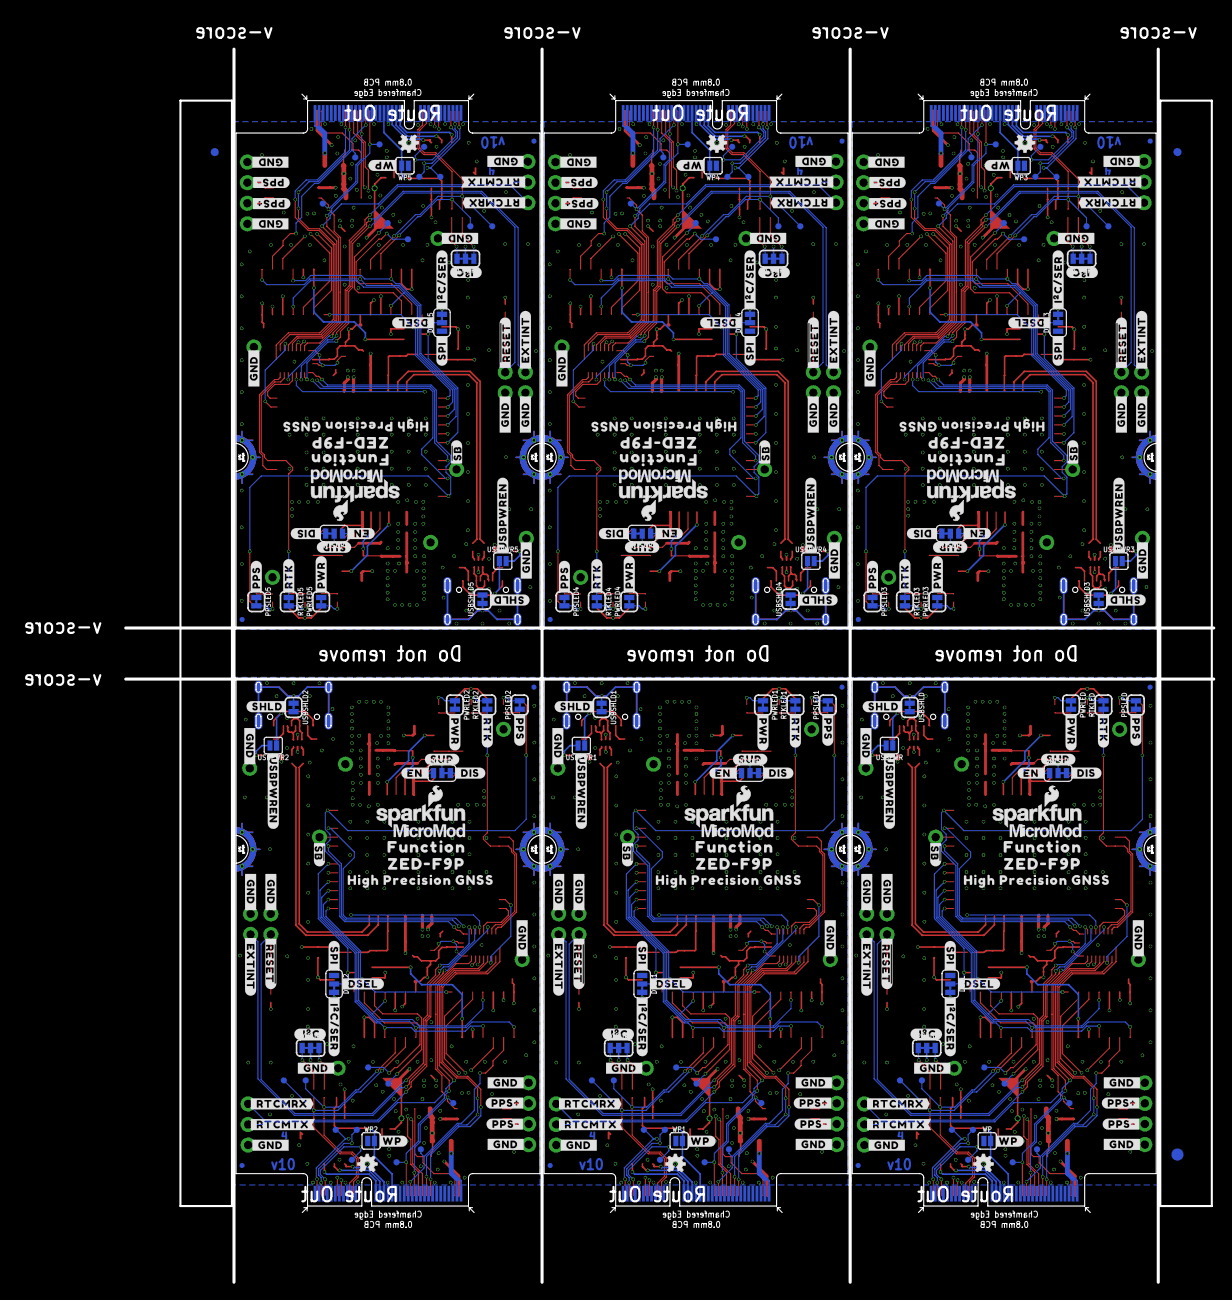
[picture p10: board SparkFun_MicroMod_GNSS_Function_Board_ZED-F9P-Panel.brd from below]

Board: 4 copper layers, 134.2 x 152.1 mm, 984 parts (339 on the bottom side), 468 nets.

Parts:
ANTSUP, ANTSUP1, ANTSUP2, ANTSUP3, ANTSUP4, ANTSUP5: JUMPER-SMT_3_1-NC_TRACE_SILK; SMT-JUMPER_3_1-NC_TRACE_SILK
BT1, BT2, BT3, BT4, BT5, BT6: RELOWABLE_BATTERY_MS421R; MS421R_IV03E
C1, C3, C9, C12, C29, C30, C31, C32, C45, C46, C47, C48, C61, C62, C63, C64, C77, C78, C79, C80, C93, C94, C95, C96: 1.0uF; 0402-TIGHT
C2, C4, C6, C7, C10, C13, C14, C15, C16, C17, C21, C22, C23, C24, C25, C26, C27, C28, C33, C37, C38, C39, C40, C41, C42, C43, C44, C49, C53, C54, C55, C56, C57, C58, C59, C60, C65, C69, C70, C71, C72, C73, C74, C75, C76, C81, C85, C86, C87, C88, C89, C90, C91, C92: 0.1uF; 0402-TIGHT
C5, C19, C35, C51, C67, C83: 10nF; 0402-TIGHT
C8, C18, C34, C50, C66, C82: 47pF; 0402-TIGHT
C11, C20, C36, C52, C68, C84: 2.2uF; 0402-TIGHT
D1, D2, D11, D14, D19, D22, D27, D30, D35, D38, D43, D46: 3A/10V/280mV; SOD-323
D3, D15, D23, D31, D39, D47: PRTR5V0U2F; SOT886
D4, D12, D20, D28, D36, D44: RED; LED-0603
D5, D6, D10, D16, D18, D24, D26, D32, D34, D40, D42, D48: BLUE; LED-0603
D7, D9, D17, D25, D33, D41: 0.5A/40V/420mV; SOD-323
D8, D13, D21, D29, D37, D45: PESD0402-0402T; 0402-TIGHT
DSEL, DSEL1, DSEL2, DSEL3, DSEL4, DSEL5: JUMPER-SMT_3_1-NC_TRACE_SILK; SMT-JUMPER_3_1-NC_TRACE_SILK
E$1, E$2, E$3, E$4: FIDUCIAL-1X2
E$5, E$6: FIDUCIAL-1.5X3
FD1, FD2, FD3, FD4, FD5, FD6, FD7, FD8, FD9, FD10, FD11, FD12, FD13, FD14, FD15, FD16, FD17, FD18, FD19, FD20, FD21, FD22, FD23, FD24: FIDUCIALUFIDUCIAL; FIDUCIAL-MICRO
FRAME1, FRAME2, FRAME3, FRAME4, FRAME5, FRAME6: FRAME-LEDGER; CREATIVE_COMMONS
I2CPUR, I2CPUR1, I2CPUR2, I2CPUR3, I2CPUR4, I2CPUR5: JUMPER-SMT_3_2-NC_TRACE_SILK; SMT-JUMPER_3_2-NC_TRACE_SILK
J1, J21, J35, J49, J63, J77: USB Female Type C Connector; USB-C-16P-4LAYER-ISOLATED
J2, J15, J29, J43, J57, J71: MICROMOD_FUNCTION_STANDARD; M.2-CARD-E-22_FUNCTION_STANDARD
J3, J4, J5, J7, J8, J11, J19, J22, J23, J24, J25, J26, J33, J36, J37, J38, J39, J40, J47, J50, J51, J52, J53, J54, J61, J64, J65, J66, J67, J68, J75, J78, J79, J80, J81, J82: 1X01_NO_SILK
J6, J28, J42, J56, J70, J84: 1X01_SMALL
J9, J16, J30, J44, J58, J72: U.FL
J10, J17, J31, J45, J59, J73: 455-1750-1-ND; 1X03_NO_SILK
J12, J13, J20, J27, J34, J41, J48, J55, J62, J69, J76, J83: 1X02_NO_SILK
J14, J18, J32, J46, J60, J74: 1X04_NO_SILK
L1, L2, L3, L4, L5, L6: 150nH; 0402_MURATA
LOGO1, LOGO6, LOGO9, LOGO12, LOGO15, LOGO18: SFE_LOGO_NAME_FLAMEBLANK; BLANK
LOGO2, LOGO3, LOGO7, LOGO10, LOGO13, LOGO16: OSHW-LOGOMINI; OSHW-LOGO-MINI
LOGO4, LOGO5, LOGO8, LOGO11, LOGO14, LOGO17: SFE_LOGO_NAME_FLAME.1_INCH; SFE_LOGO_NAME_FLAME_.1
PPSLED, PPSLED1, PPSLED2, PPSLED3, PPSLED4, PPSLED5: JUMPER-SMT_2_NC_TRACE_SILK; SMT-JUMPER_2_NC_TRACE_SILK
PWRLED, PWRLED1, PWRLED2, PWRLED3, PWRLED4, PWRLED5: JUMPER-SMT_2_NC_TRACE_SILK; SMT-JUMPER_2_NC_TRACE_SILK
Q1, Q2, Q3, Q4, Q5, Q6: DMP21D0UT-7; SOT523
R1, R2, R13, R14, R20, R21, R22, R32, R33, R34, R37, R39, R43, R53, R54, R55, R58, R60, R64, R74, R75, R76, R79, R81, R85, R95, R96, R97, R100, R102, R106, R116, R117, R118, R121, R123: 10k; 0402-TIGHT
R3, R4, R23, R24, R44, R45, R65, R66, R86, R87, R107, R108: 5.1k; 0402-TIGHT
R5, R27, R48, R69, R90, R111: 3.3K; 0402-TIGHT
R6, R15, R36, R38, R57, R59, R78, R80, R99, R101, R120, R122: 1k; 0402-TIGHT
R7, R8, R28, R40, R49, R61, R70, R82, R91, R103, R112, R124: 4.7k; 0402-TIGHT
R9, R10, R25, R26, R46, R47, R67, R68, R88, R89, R109, R110: 27; 0402-TIGHT
R11, R12, R41, R42, R62, R63, R83, R84, R104, R105, R125, R126: 2.2k; 0402-TIGHT
R16, R30, R51, R72, R93, R114: 100k; 0402-TIGHT
R17, R31, R52, R73, R94, R115: 10; 0603
R18, R35, R56, R77, R98, R119: 22k; 0402-TIGHT
R19, R29, R50, R71, R92, R113: 47k; 0402-TIGHT
RTKLED, RTKLED1, RTKLED2, RTKLED3, RTKLED4, RTKLED5: JUMPER-SMT_2_NC_TRACE_SILK; SMT-JUMPER_2_NC_TRACE_SILK
TP1, TP2, TP3, TP4, TP5, TP6, TP7, TP8, TP9, TP10, TP11, TP12, TP13, TP14, TP15, TP16, TP17, TP18, TP19, TP20, TP21, TP22, TP23, TP24, TP25, TP26, TP27, TP28, TP29, TP30, TP31, TP32, TP33, TP34, TP35, TP36, TP37, TP38, TP39, TP40, TP41, TP42, TP43, TP44, TP45, TP46, TP47, TP48, TP49, TP50, TP51, TP52, TP53, TP54, TP55, TP56, TP57, TP58, TP59, TP60: TEST-POINT3; PAD.03X.03
U1, U22, U33, U44, U55, U66: NLAST4501DFT2G; SOT353
U2, U19, U30, U41, U52, U63: 3.3V; SOT23-5
U3, U12, U23, U34, U45, U56: EEPROM; SO08
U4, U5, U20, U21, U31, U32, U42, U43, U53, U54, U64, U65: 74LVC4066D_QUAD_BILATERAL_SWITCH; SO14
U6, U17, U28, U39, U50, U61: OPA344; SOT23-5
U7, U14, U25, U36, U47, U58: 74LVC541A; DHVQFN20
U8, U15, U26, U37, U48, U59: U-BLOX_ZED-F9P; ZED-F9P
U9, U16, U27, U38, U49, U60: FIN1017MX; SO08
U10, U11, U13, U18, U24, U29, U35, U40, U46, U51, U57, U62: SN74AUP1T04; SC-70-5_DCK
U$1, U$119, U$182, U$245, U$308, U$371: 40
U$2, U$92, U$159, U$222, U$285, U$348: #_RTCMTX#0
U$3, U$93, U$160, U$223, U$286, U$349: #TX2_#0
U$4, U$8, U$37, U$63, U$127, U$128, U$190, U$191, U$253, U$254, U$316, U$317: MICROMOD_LOGO_.35
U$5, U$6, U$7, U$9, U$10, U$11, U$18, U$19, U$21, U$22, U$25, U$33, U$38, U$39, U$94, U$95, U$96, U$97, U$98, U$99, U$108, U$109, U$110, U$111, U$116, U$123, U$124, U$125, U$161, U$162, U$163, U$164, U$165, U$166, U$173, U$174, U$175, U$176, U$179, U$186, U$187, U$188, U$224, U$225, U$226, U$227, U$228, U$229, U$236, U$237, U$238, U$239, U$242, U$249, U$250, U$251, U$287, U$288, U$289, U$290, U$291, U$292, U$299, U$300, U$301, U$302, U$305, U$312, U$313, U$314, U$350, U$351, U$352, U$353, U$354, U$355, U$362, U$363, U$364, U$365, U$368, U$375, U$376, U$377: #_GND_#0
U$12, U$100, U$167, U$230, U$293, U$356: #_RTCMRX#0
U$13, U$101, U$168, U$231, U$294, U$357: #RX2_#0
U$14, U$102, U$169, U$232, U$295, U$358: ##RESET_##0
U$15, U$103, U$170, U$233, U$296, U$359: #_#RESET##0
U$16, U$105, U$171, U$234, U$297, U$360: #_EXTINT#0
U$17, U$107, U$172, U$235, U$298, U$361: #EXTINT_#0
U$20, U$26, U$27, U$41, U$129, U$130, U$192, U$193, U$255, U$256, U$318, U$319: FUNCTION0
U$23, U$113, U$177, U$240, U$303, U$366: #_I�C#SER#0
U$24, U$115, U$178, U$241, U$304, U$367: #SPI_#0
U$28, U$117, U$180, U$243, U$306, U$369: #_I�C#0
U$29, U$118, U$181, U$244, U$307, U$370: #_DSEL#0
U$30, U$120, U$183, U$246, U$309, U$372: #SUP#0
U$31, U$121, U$184, U$247, U$310, U$373: #RTK#0
U$32, U$122, U$185, U$248, U$311, U$374: #PWR#0
U$34, U$42, U$131, U$194, U$257, U$320: 10
U$35, U$43, U$132, U$195, U$258, U$321: 211
U$36, U$53, U$133, U$196, U$259, U$322: 3212
U$40, U$126, U$189, U$252, U$315, U$378: PPS3
U$44, U$60, U$139, U$202, U$265, U$328: #PPS##2252
U$45, U$61, U$140, U$203, U$266, U$329: #PPS##2253
U$46, U$47, U$55, U$56, U$134, U$135, U$197, U$198, U$260, U$261, U$323, U$324: G2
U$48, U$57, U$136, U$199, U$262, U$325: #3
U$49, U$58, U$137, U$200, U$263, U$326: #4
U$50, U$65, U$141, U$204, U$267, U$330: #PPS#2254
U$51, U$66, U$142, U$205, U$268, U$331: PPS0
U$52, U$67, U$143, U$206, U$269, U$332: RTK0
U$54, U$81, U$151, U$214, U$277, U$340: #WP#0
U$59, U$104, U$138, U$201, U$264, U$327: SFE_LOGO_FLAME_STOP_.1
U$62, U$70, U$145, U$208, U$271, U$334: #USBPWREN#10
U$64, U$71, U$146, U$209, U$272, U$335: #SHLD#12
U$68, U$89, U$156, U$219, U$282, U$345: #VZED#0
U$69, U$76, U$144, U$207, U$270, U$333: ##SB##9
U$72, U$79, U$150, U$213, U$276, U$339: PWR0
U$73, U$90, U$157, U$220, U$283, U$346: #_DIS#0
U$74, U$91, U$158, U$221, U$284, U$347: #EN_#0
U$75, U$106, U$147, U$210, U$273, U$336: HIGH_PRECISION_GNSS26
U$77, U$78, U$112, U$114, U$148, U$149, U$211, U$212, U$274, U$275, U$337, U$338: ZED#F9P0
U$80, U$83, U$152, U$215, U$278, U$341: ##SB##0
U$82, U$84, U$153, U$216, U$279, U$342: #GND#0
U$85, U$86, U$154, U$217, U$280, U$343: L1#L20
U$87, U$88, U$155, U$218, U$281, U$344: ANTENNA0
USBPWR, USBPWR1, USBPWR2, USBPWR3, USBPWR4, USBPWR5: JUMPER-SMT_2_NO_SILK; SMT-JUMPER_2_NO_SILK
USBSHLD, USBSHLD1, USBSHLD2, USBSHLD3, USBSHLD4, USBSHLD5: JUMPER-SMT_2_NC_TRACE_SILK; SMT-JUMPER_2_NC_TRACE_SILK
WP, WP1, WP2, WP3, WP4, WP5: JUMPER-SMT_2_NO_SILK; SMT-JUMPER_2_NO_SILK

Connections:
3.3V: C2.1, C14.1, D7.A, J2.73, R1.1, U3.8, U9.1
3.3V1: C23.1, C24.1, D9.A, J15.73, R22.1, U12.8, U16.1
3.3V2: C39.1, C40.1, D17.A, J29.73, R43.1, U23.8, U27.1
3.3V3: C55.1, C56.1, D25.A, J43.73, R64.1, U34.8, U38.1
3.3V4: C71.1, C72.1, D33.A, J57.73, R85.1, U45.8, U49.1
3.3V5: C87.1, C88.1, D41.A, J71.73, R106.1, U56.8, U60.1
5V: C1.1, D1.C, D2.C, R2.1, U2.1
5V1: C31.1, D11.C, D14.C, R37.1, U19.1
5V2: C47.1, D19.C, D22.C, R58.1, U30.1
5V3: C63.1, D27.C, D30.C, R79.1, U41.1
5V4: C79.1, D35.C, D38.C, R100.1, U52.1
5V5: C95.1, D43.C, D46.C, R121.1, U63.1
!RESET!: J2.53, J12.1, R20.2, U7.3
!RESET!1: J15.53, J27.1, R39.2, U14.3
!RESET!2: J29.53, J41.1, R60.2, U25.3
!RESET!3: J43.53, J55.1, R81.2, U36.3
!RESET!4: J57.53, J69.1, R102.2, U47.3
!RESET!5: J71.53, J83.1, R123.2, U58.3
!ZED_DSEL!: U5.5, U5.6, U5.12, U5.13, U11.4
!ZED_DSEL!1: U18.4, U21.5, U21.6, U21.12, U21.13
!ZED_DSEL!2: U29.4, U32.5, U32.6, U32.12, U32.13
!ZED_DSEL!3: U40.4, U43.5, U43.6, U43.12, U43.13
!ZED_DSEL!4: U51.4, U54.5, U54.6, U54.12, U54.13
!ZED_DSEL!5: U62.4, U65.5, U65.6, U65.12, U65.13
A0: J2.36, U3.1
A1: J2.34, U3.2
A2: J2.32, U3.3
A3: J15.36, U12.1
A4: J15.32, U12.3
A5: J15.34, U12.2
A6: J29.36, U23.1
A7: J29.32, U23.3
A8: J29.34, U23.2
A9: J43.36, U34.1
A10: J43.32, U34.3
A11: J43.34, U34.2
A12: J57.36, U45.1
A13: J57.32, U45.3
A14: J57.34, U45.2
A15: J71.36, U56.1
A16: J71.32, U56.3
A17: J71.34, U56.2
EWP: J2.40, R1.2, U3.7, WP.2
EWP1: J15.40, R22.2, U12.7, WP1.2
EWP2: J29.40, R43.2, U23.7, WP2.2
EWP3: J43.40, R64.2, U34.7, WP3.2
EWP4: J57.40, R85.2, U45.7, WP4.2
EWP5: J71.40, R106.2, U56.7, WP5.2
EXTINT: J2.55, J13.1, U7.4
EXTINT1: J15.55, J20.1, U14.4
EXTINT2: J29.55, J34.1, U25.4
EXTINT3: J43.55, J48.1, U36.4
EXTINT4: J57.55, J62.1, U47.4
EXTINT5: J71.55, J76.1, U58.4
GEO_STAT: J2.59, U7.11
GEO_STAT1: J15.59, U14.11
GEO_STAT2: J29.59, U25.11
GEO_STAT3: J43.59, U36.11
GEO_STAT4: J57.59, U47.11
GEO_STAT5: J71.59, U58.11
GND: BT1.-, C1.2, C2.2, C3.2, C4.2, C5.2, C6.2, C7.2, C9.2, C10.2, C11.2, C12.2, C13.2, C14.2, C15.2, C16.2, D3.2, D8.2, DSEL.1, J1.GND, J1.GND2, J2.1, J2.33, J2.39, J2.45, J2.75, J2.GND1, J2.GND2, J2.GND3, J2.GND4, J2.GND5, J2.GND6, J4.1, J5.1, J7.1, J8.1, J9.1, J9.2, J10.3, J12.2, J13.2, J14.1, J14.4, PPSLED.1, PWRLED.2, R3.1, R4.1, R14.1, R16.1, R19.1, U1.3, U2.2, U3.4, U4.7, U5.7, U6.2, U7.10, U7.EPAD, U8.1, U8.3, U8.12, U8.14, U8.32, U8.37, U8.41, U8.48, U8.55, U8.56, U8.57, U8.58, U8.59, U8.60, U8.61, U8.62, U8.63, U8.64, U8.65, U8.66, U8.67, U8.68, U8.69, U8.70, U8.71, U8.72, U8.73, U8.74, U8.75, U8.76, U8.77, U8.78, U8.79, U8.80, U8.81, U8.82, U8.83, U8.84, U8.85, U8.86, U8.87, U8.88, U8.89, U8.90, U8.91, U8.92, U8.93, U8.94, U8.95, U8.96, U8.97, U8.98, U8.99, U8.100, U8.101, U8.102, U9.4, U10.3, U11.3, USBSHLD.2, WP.1
GND1: BT2.-, C17.2, C19.2, C20.2, C21.2, C22.2, C23.2, C24.2, C25.2, C26.2, C27.2, C28.2, C29.2, C30.2, C31.2, C32.2, D13.2, D15.2, DSEL1.1, J15.1, J15.33, J15.39, J15.45, J15.75, J15.GND1, J15.GND2, J15.GND3, J15.GND4, J15.GND5, J15.GND6, J16.1, J16.2, J17.3, J18.1, J18.4, J20.2, J21.GND, J21.GND2, J23.1, J24.1, J25.1, J26.1, J27.2, PPSLED1.1, PWRLED1.2, R23.1, R24.1, R29.1, R30.1, R34.1, U12.4, U13.3, U14.10, U14.EPAD, U15.1, U15.3, U15.12, U15.14, U15.32, U15.37, U15.41, U15.48, U15.55, U15.56, U15.57, U15.58, U15.59, U15.60, U15.61, U15.62, U15.63, U15.64, U15.65, U15.66, U15.67, U15.68, U15.69, U15.70, U15.71, U15.72, U15.73, U15.74, U15.75, U15.76, U15.77, U15.78, U15.79, U15.80, U15.81, U15.82, U15.83, U15.84, U15.85, U15.86, U15.87, U15.88, U15.89, U15.90, U15.91, U15.92, U15.93, U15.94, U15.95, U15.96, U15.97, U15.98, U15.99, U15.100, U15.101, U15.102, U16.4, U17.2, U18.3, U19.2, U20.7, U21.7, U22.3, USBSHLD1.2, WP1.1
GND2: BT3.-, C33.2, C35.2, C36.2, C37.2, C38.2, C39.2, C40.2, C41.2, C42.2, C43.2, C44.2, C45.2, C46.2, C47.2, C48.2, D21.2, D23.2, DSEL2.1, J29.1, J29.33, J29.39, J29.45, J29.75, J29.GND1, J29.GND2, J29.GND3, J29.GND4, J29.GND5, J29.GND6, J30.1, J30.2, J31.3, J32.1, J32.4, J34.2, J35.GND, J35.GND2, J37.1, J38.1, J39.1, J40.1, J41.2, PPSLED2.1, PWRLED2.2, R44.1, R45.1, R50.1, R51.1, R55.1, U23.4, U24.3, U25.10, U25.EPAD, U26.1, U26.3, U26.12, U26.14, U26.32, U26.37, U26.41, U26.48, U26.55, U26.56, U26.57, U26.58, U26.59, U26.60, U26.61, U26.62, U26.63, U26.64, U26.65, U26.66, U26.67, U26.68, U26.69, U26.70, U26.71, U26.72, U26.73, U26.74, U26.75, U26.76, U26.77, U26.78, U26.79, U26.80, U26.81, U26.82, U26.83, U26.84, U26.85, U26.86, U26.87, U26.88, U26.89, U26.90, U26.91, U26.92, U26.93, U26.94, U26.95, U26.96, U26.97, U26.98, U26.99, U26.100, U26.101, U26.102, U27.4, U28.2, U29.3, U30.2, U31.7, U32.7, U33.3, USBSHLD2.2, WP2.1
GND3: BT4.-, C49.2, C51.2, C52.2, C53.2, C54.2, C55.2, C56.2, C57.2, C58.2, C59.2, C60.2, C61.2, C62.2, C63.2, C64.2, D29.2, D31.2, DSEL3.1, J43.1, J43.33, J43.39, J43.45, J43.75, J43.GND1, J43.GND2, J43.GND3, J43.GND4, J43.GND5, J43.GND6, J44.1, J44.2, J45.3, J46.1, J46.4, J48.2, J49.GND, J49.GND2, J51.1, J52.1, J53.1, J54.1, J55.2, PPSLED3.1, PWRLED3.2, R65.1, R66.1, R71.1, R72.1, R76.1, U34.4, U35.3, U36.10, U36.EPAD, U37.1, U37.3, U37.12, U37.14, U37.32, U37.37, U37.41, U37.48, U37.55, U37.56, U37.57, U37.58, U37.59, U37.60, U37.61, U37.62, U37.63, U37.64, U37.65, U37.66, U37.67, U37.68, U37.69, U37.70, U37.71, U37.72, U37.73, U37.74, U37.75, U37.76, U37.77, U37.78, U37.79, U37.80, U37.81, U37.82, U37.83, U37.84, U37.85, U37.86, U37.87, U37.88, U37.89, U37.90, U37.91, U37.92, U37.93, U37.94, U37.95, U37.96, U37.97, U37.98, U37.99, U37.100, U37.101, U37.102, U38.4, U39.2, U40.3, U41.2, U42.7, U43.7, U44.3, USBSHLD3.2, WP3.1
GND4: BT5.-, C65.2, C67.2, C68.2, C69.2, C70.2, C71.2, C72.2, C73.2, C74.2, C75.2, C76.2, C77.2, C78.2, C79.2, C80.2, D37.2, D39.2, DSEL4.1, J57.1, J57.33, J57.39, J57.45, J57.75, J57.GND1, J57.GND2, J57.GND3, J57.GND4, J57.GND5, J57.GND6, J58.1, J58.2, J59.3, J60.1, J60.4, J62.2, J63.GND, J63.GND2, J65.1, J66.1, J67.1, J68.1, J69.2, PPSLED4.1, PWRLED4.2, R86.1, R87.1, R92.1, R93.1, R97.1, U45.4, U46.3, U47.10, U47.EPAD, U48.1, U48.3, U48.12, U48.14, U48.32, U48.37, U48.41, U48.48, U48.55, U48.56, U48.57, U48.58, U48.59, U48.60, U48.61, U48.62, U48.63, U48.64, U48.65, U48.66, U48.67, U48.68, U48.69, U48.70, U48.71, U48.72, U48.73, U48.74, U48.75, U48.76, U48.77, U48.78, U48.79, U48.80, U48.81, U48.82, U48.83, U48.84, U48.85, U48.86, U48.87, U48.88, U48.89, U48.90, U48.91, U48.92, U48.93, U48.94, U48.95, U48.96, U48.97, U48.98, U48.99, U48.100, U48.101, U48.102, U49.4, U50.2, U51.3, U52.2, U53.7, U54.7, U55.3, USBSHLD4.2, WP4.1
GND5: BT6.-, C81.2, C83.2, C84.2, C85.2, C86.2, C87.2, C88.2, C89.2, C90.2, C91.2, C92.2, C93.2, C94.2, C95.2, C96.2, D45.2, D47.2, DSEL5.1, J71.1, J71.33, J71.39, J71.45, J71.75, J71.GND1, J71.GND2, J71.GND3, J71.GND4, J71.GND5, J71.GND6, J72.1, J72.2, J73.3, J74.1, J74.4, J76.2, J77.GND, J77.GND2, J79.1, J80.1, J81.1, J82.1, J83.2, PPSLED5.1, PWRLED5.2, R107.1, R108.1, R113.1, R114.1, R118.1, U56.4, U57.3, U58.10, U58.EPAD, U59.1, U59.3, U59.12, U59.14, U59.32, U59.37, U59.41, U59.48, U59.55, U59.56, U59.57, U59.58, U59.59, U59.60, U59.61, U59.62, U59.63, U59.64, U59.65, U59.66, U59.67, U59.68, U59.69, U59.70, U59.71, U59.72, U59.73, U59.74, U59.75, U59.76, U59.77, U59.78, U59.79, U59.80, U59.81, U59.82, U59.83, U59.84, U59.85, U59.86, U59.87, U59.88, U59.89, U59.90, U59.91, U59.92, U59.93, U59.94, U59.95, U59.96, U59.97, U59.98, U59.99, U59.100, U59.101, U59.102, U60.4, U61.2, U62.3, U63.2, U64.7, U65.7, U66.3, USBSHLD5.2, WP5.1
IO_!OE!: U7.1, U7.19, U10.4
IO_!OE!1: U13.4, U14.1, U14.19
IO_!OE!2: U24.4, U25.1, U25.19
IO_!OE!3: U35.4, U36.1, U36.19
IO_!OE!4: U46.4, U47.1, U47.19
IO_!OE!5: U57.4, U58.1, U58.19
MM_!CS!: J2.49, TP11.1, U5.2
MM_!CS!1: J15.49, TP19.1, U21.2
MM_!CS!2: J29.49, TP29.1, U32.2
MM_!CS!3: J43.49, TP39.1, U43.2
MM_!CS!4: J57.49, TP49.1, U54.2
MM_!CS!5: J71.49, TP59.1, U65.2
MM_PICO: J2.5, TP12.1, U5.10
MM_PICO1: J15.5, TP16.1, U21.10
MM_PICO2: J29.5, TP26.1, U32.10
MM_PICO3: J43.5, TP36.1, U43.10
MM_PICO4: J57.5, TP46.1, U54.10
MM_PICO5: J71.5, TP56.1, U65.10
MM_POCI: J2.7, TP13.1, U5.9
MM_POCI1: J15.7, TP17.1, U21.9
MM_POCI2: J29.7, TP27.1, U32.9
MM_POCI3: J43.7, TP37.1, U43.9
MM_POCI4: J57.7, TP47.1, U54.9
MM_POCI5: J71.7, TP57.1, U65.9
MM_RX: J2.15, TP7.1, U4.10
MM_RX1: J15.15, TP2.1, U20.10
MM_RX2: J29.15, TP22.1, U31.10
MM_RX3: J43.15, TP32.1, U42.10
MM_RX4: J57.15, TP42.1, U53.10
MM_RX5: J71.15, TP52.1, U64.10
MM_SCK: J2.3, TP10.1, U5.3
MM_SCK1: J15.3, TP18.1, U21.3
MM_SCK2: J29.3, TP28.1, U32.3
MM_SCK3: J43.3, TP38.1, U43.3
MM_SCK4: J57.3, TP48.1, U54.3
MM_SCK5: J71.3, TP58.1, U65.3
MM_SCL: J2.21, R11.1, TP5.1, U3.6, U4.3
MM_SCL1: J15.21, R41.1, TP4.1, U12.6, U20.3
MM_SCL2: J29.21, R62.1, TP24.1, U23.6, U31.3
MM_SCL3: J43.21, R83.1, TP34.1, U34.6, U42.3
MM_SCL4: J57.21, R104.1, TP44.1, U45.6, U53.3
MM_SCL5: J71.21, R125.1, TP54.1, U56.6, U64.3
MM_SDA: J2.19, R12.1, TP6.1, U3.5, U4.2
MM_SDA1: J15.19, R42.1, TP15.1, U12.5, U20.2
MM_SDA2: J29.19, R63.1, TP25.1, U23.5, U31.2
MM_SDA3: J43.19, R84.1, TP35.1, U34.5, U42.2
MM_SDA4: J57.19, R105.1, TP45.1, U45.5, U53.2
MM_SDA5: J71.19, R126.1, TP55.1, U56.5, U64.2
MM_TX: J2.13, TP8.1, U4.9
MM_TX1: J15.13, TP3.1, U20.9
MM_TX2: J29.13, TP23.1, U31.9
MM_TX3: J43.13, TP33.1, U42.9
MM_TX4: J57.13, TP43.1, U53.9
MM_TX5: J71.13, TP53.1, U64.9
unnamed: ANTSUP.1, R13.1
unnamed: ANTSUP.3, R14.2
unnamed: J1.B5, R3.2
unnamed: J1.A5, R4.2
unnamed: DSEL.3, R21.1
unnamed: I2CPUR.3, R11.2
unnamed: C8.1, D8.1, J9.FEED, L1.2
unnamed: R7.1, RTKLED.2
unnamed: I2CPUR.1, R12.2
unnamed: J21.B5, R23.2
unnamed: J21.A5, R24.2
unnamed: D9.C, R27.2
unnamed: Q1.1, R15.1, R17.1
unnamed: C9.1, C10.1, R18.2, R19.2, U8.38
unnamed: R28.1, RTKLED1.2
unnamed: D2.A, USBPWR.2
unnamed: D10.C, R28.2
unnamed: PWRLED1.1, R38.1
unnamed: D12.C, R38.2
unnamed: R30.2, R36.2, U17.3
unnamed: Q2.1, R31.1, R36.1
unnamed: C18.1, D13.1, J16.FEED, L2.2
unnamed: D14.A, USBPWR1.2
unnamed: C17.1, C30.1, R29.2, R35.2, U15.38
unnamed: ANTSUP1.1, R33.1
unnamed: PWRLED.1, R6.1
unnamed: PPSLED.2, R8.1
unnamed: D6.C, R8.2
unnamed: D5.C, R7.2
unnamed: D4.C, R6.2
unnamed: ANTSUP1.3, R34.2
unnamed: D7.C, R5.2
unnamed: DSEL1.3, R32.1
unnamed: PPSLED1.2, R40.1
unnamed: D16.C, R40.2
unnamed: I2CPUR1.3, R41.2
unnamed: I2CPUR1.1, R42.2
unnamed: J35.B5, R44.2
unnamed: J35.A5, R45.2
unnamed: D17.C, R48.2
unnamed: R49.1, RTKLED2.2
unnamed: D18.C, R49.2
unnamed: PWRLED2.1, R59.1
unnamed: D20.C, R59.2
unnamed: R51.2, R57.2, U28.3
unnamed: Q3.1, R52.1, R57.1
unnamed: C34.1, D21.1, J30.FEED, L3.2
unnamed: R15.2, R16.2, U6.3
unnamed: D22.A, USBPWR2.2
unnamed: C33.1, C46.1, R50.2, R56.2, U26.38
unnamed: ANTSUP2.1, R54.1
unnamed: ANTSUP2.3, R55.2
unnamed: DSEL2.3, R53.1
unnamed: PPSLED2.2, R61.1
unnamed: D24.C, R61.2
unnamed: I2CPUR2.3, R62.2
unnamed: I2CPUR2.1, R63.2
unnamed: J49.B5, R65.2
unnamed: J49.A5, R66.2
unnamed: D25.C, R69.2
unnamed: R70.1, RTKLED3.2
unnamed: D26.C, R70.2
unnamed: PWRLED3.1, R80.1
unnamed: D28.C, R80.2
unnamed: R72.2, R78.2, U39.3
unnamed: Q4.1, R73.1, R78.1
unnamed: C50.1, D29.1, J44.FEED, L4.2
unnamed: D30.A, USBPWR3.2
unnamed: C49.1, C62.1, R71.2, R77.2, U37.38
unnamed: ANTSUP3.1, R75.1
unnamed: ANTSUP3.3, R76.2
unnamed: DSEL3.3, R74.1
unnamed: PPSLED3.2, R82.1
unnamed: D32.C, R82.2
unnamed: I2CPUR3.3, R83.2
unnamed: I2CPUR3.1, R84.2
unnamed: J63.B5, R86.2
unnamed: J63.A5, R87.2
unnamed: D33.C, R90.2
unnamed: R91.1, RTKLED4.2
unnamed: D34.C, R91.2
unnamed: PWRLED4.1, R101.1
unnamed: D36.C, R101.2
unnamed: R93.2, R99.2, U50.3
unnamed: Q5.1, R94.1, R99.1
unnamed: C66.1, D37.1, J58.FEED, L5.2
unnamed: D38.A, USBPWR4.2
unnamed: C65.1, C78.1, R92.2, R98.2, U48.38
unnamed: ANTSUP4.1, R96.1
unnamed: ANTSUP4.3, R97.2
unnamed: DSEL4.3, R95.1
unnamed: PPSLED4.2, R103.1
unnamed: D40.C, R103.2
unnamed: I2CPUR4.3, R104.2
unnamed: I2CPUR4.1, R105.2
unnamed: J77.B5, R107.2
unnamed: J77.A5, R108.2
unnamed: D41.C, R111.2
unnamed: R112.1, RTKLED5.2
unnamed: D42.C, R112.2
unnamed: PWRLED5.1, R122.1
unnamed: D44.C, R122.2
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

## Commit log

2022-03-10 Created blank hardware files.
    [SparkFun_MicroMod_Function_ZED-F9P.brd, SparkFun_MicroMod_Function_ZED-F9P.sch]
2022-03-14 Added EEPROM. Added LEDs. Added Module. Added Backup Battery. Added USB-C connector. Added Qwiic connector. Added GNSS App Note.
    [SparkFun_MicroMod_Function_ZED-F9P.brd, SparkFun_MicroMod_Function_ZED-F9P.sch]
2022-03-16 Added I2C protection for ZED_F9P
    [SparkFun_MicroMod_Function_ZED-F9P.brd, SparkFun_MicroMod_Function_ZED-F9P.sch]
2022-03-18 Created local library. Added ZED-F9P to sch.
    Created Local library.
    Added inverter to lib.
    Added octal buffer to lib.
    Added modified ZED-F9P to lib.
    Added ZED-F9P to sch.
    [SparkFun_MicroMod_Function_ZED-F9P.brd, SparkFun_MicroMod_Function_ZED-F9P.sch]
2022-03-19 Filled out octal buffers, labeled nets. Modified inverter sch symbol.
    [SparkFun_MicroMod_Function_ZED-F9P.brd, SparkFun_MicroMod_Function_ZED-F9P.sch]
2022-03-19 Added I/O and passives. Changed net names.
    Added passives surrounding IC's.
    Modified names to be more descriptive.
    Reorganized schematic for visual representation.
    Added Descriptions of schematic symbols.
    [SparkFun_MicroMod_Function_ZED-F9P.brd, SparkFun_MicroMod_Function_ZED-F9P.sch]
2022-03-21 Completed antenna supervisor. Started External Antenna Power.
    [SparkFun_MicroMod_Function_ZED-F9P.brd, SparkFun_MicroMod_Function_ZED-F9P.sch]
2022-03-23 Commit for current progress.
    Committing so others can begin a schematic review while I finish up.
    [SparkFun_MicroMod_Function_ZED-F9P.brd, SparkFun_MicroMod_Function_ZED-F9P.sch]
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2022-03-24 Added Correct Version to sch.
    [SparkFun_MicroMod_Function_ZED-F9P.sch]
2022-03-25 Changed power resistor, needed higher power rating.
    [SparkFun_MicroMod_Function_ZED-F9P.brd, SparkFun_MicroMod_Function_ZED-F9P.sch]
2022-03-25 Ran ERC and updated.
    Needed to re-place U3 parts. Needed to approve warnings/errors.
    [SparkFun_MicroMod_Function_ZED-F9P.sch]
2022-03-25 Updated Schematic for ERC and comments from Paul.
    Created NO jumper on USB-C shield/gnd tie.
    Updated some power connections for style.
    Deleted $ from designations.
    Reworded ANT_OFF comment.
    Repositioned ANT_!SHORT! net.
    Floated U9Y7 output.
    Renamed version back to v01 per SFE standards.
    Changed proportional text to vector.
    Ran and mitigated ERC.
    Reworded LED comment.
    Deleted unused wires.
    [SparkFun_MicroMod_Function_ZED-F9P.sch]
2022-03-28 Update Post schematic review.
    Made all easy changes, in midst of redoing decoupling per requests.
    [SparkFun_MicroMod_Function_ZED-F9P.brd, SparkFun_MicroMod_Function_ZED-F9P.sch]
2022-03-30 Complete schematic after DR changes.
    Reorganized power: changed supply, removed fuse, replaced usb_det supply with voltage divider, renamed power nets.
    Added TPs and PTH breakouts for some pins.
    Changed I/O decoupling: Replaced octal buffer with 2x quad SSR switches, removed buffer on antenna supervision, rearranged pins on remaining octal buffer.
    Labeled diff PPS signal.
    Added second Qwiic connector.
    Added selector headers for bus and antenna supervisor circuits.
    Removed extra LEDs.
    Replaced SMA with u.FL.
    [SparkFun_MicroMod_Function_ZED-F9P.brd, SparkFun_MicroMod_Function_ZED-F9P.sch]
2022-03-30 Update selector wording per PC.
    [SparkFun_MicroMod_Function_ZED-F9P.sch]
2022-03-30 ERC run and fixes applied.
    Forgot to do that before previous commit.
    [SparkFun_MicroMod_Function_ZED-F9P.sch]
2022-03-31 First day of layout.
    Laid out most of the board with airwires. Have a rough idea of grounding so far so good. Have had to replace a fair bit of components for smaller ones. Those 0603's look massive on such a small board.
    [SparkFun_MicroMod_Function_ZED-F9P.brd, SparkFun_MicroMod_Function_ZED-F9P.sch]
2022-03-31 Everything tentatively placed on board.
    [SparkFun_MicroMod_Function_ZED-F9P.brd, SparkFun_MicroMod_Function_ZED-F9P.sch]
2022-03-31 1st draft power planes.
    Added split power planes to layout on inner layers.
    [SparkFun_MicroMod_Function_ZED-F9P.brd, SparkFun_MicroMod_Function_ZED-F9P.sch]
2022-04-11 Board updates from time off.
    Airport board layout was time well spent.
    [SparkFun_MicroMod_Function_ZED-F9P.brd, SparkFun_MicroMod_Function_ZED-F9P.sch]
2022-04-12 Update sch after fixing lib.
    [SparkFun_MicroMod_Function_ZED-F9P.sch]
2022-04-12 End of day commit.
    Rearchitected plane placement based on rank.
    Began routing digital signals to end points.
    [SparkFun_MicroMod_Function_ZED-F9P.brd]
2022-04-12 Replace backup battery.
    New part now in use.
    [SparkFun_MicroMod_Function_ZED-F9P.sch]
2022-04-12 All traces routed.
    All traces routed, now need to just finish up via stitching, grounding, then silks.
    [SparkFun_MicroMod_Function_ZED-F9P.brd]
2022-04-12 Change net class for vbatt.
    [SparkFun_MicroMod_Function_ZED-F9P.brd, SparkFun_MicroMod_Function_ZED-F9P.sch]
2022-04-13 GND stitching and grounding complete.
    Outer GND plane stitching complete.
    [SparkFun_MicroMod_Function_ZED-F9P.brd, SparkFun_MicroMod_Function_ZED-F9P.sch]
2022-04-13 Stitching of GND_RF complete.
    [SparkFun_MicroMod_Function_ZED-F9P.brd]
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2022-04-15 End of Day commit.
    Got Buzzard working. Added a couple labels.
    [SparkFun_MicroMod_Function_ZED-F9P.brd]
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2022-04-18 Update New Parts Lib.
    Added missing information for new parts to get them ready to be part of normal libraries. Updated schematic and board accordingly.
    [SparkFun_MicroMod_Function_ZED-F9P.brd, SparkFun_MicroMod_Function_ZED-F9P.sch]
2022-04-18 Update post 1st board checklist.
    [SparkFun_MicroMod_Function_ZED-F9P.brd, SparkFun_MicroMod_Function_ZED-F9P.sch]
2022-04-19 Update post board checker.
    Update PCB/Schematic based off feedback from the python checker tool. Also added in a few more ground vias on the RF ground plane to fill in some pour regions.
    [SparkFun_MicroMod_Function_ZED-F9P.brd, SparkFun_MicroMod_Function_ZED-F9P.sch]
2022-04-19 Changed the layer stackup ordering.
    [SparkFun_MicroMod_Function_ZED-F9P.brd]
2022-04-27 Renamed for release. Some updates post DR.
    [SparkFun_MicroMod_GNSS_Function_Board_ZED-F9P.brd, SparkFun_MicroMod_GNSS_Function_Board_ZED-F9P.sch]
2022-05-02 Add part, update lib, resize sch parts, bulk brd update.
    Add NLAST SPST switch.
    Update POCI/PICO.
    Make all resistors possible 0402. (Only 10ohm and 68.1k res are still 0603)
    [SparkFun_MicroMod_GNSS_Function_Board_ZED-F9P.brd, SparkFun_MicroMod_GNSS_Function_Board_ZED-F9P.sch]
2022-05-03 Completed updates post DR.
    Change PPS LED to Yellow.
    U1 make power V_USB, not V_ZED.
    Add PUR on PWR_EN.
    Remove TPs where PTH exists.
    Remove Qwiic connectors.
    Change U1 to be a bigger package.
    Change CIPO/COPI to PICO/POCI.
    Route out from center of pad.
    Remove silk from PTHs.
    Fix skinny VIN trace.
    Change 0.2mm vias to 0.3mm vias.
    Change 0.35mm vias to 0.3mm vias where possible.
    Set layers correctly on board so 2 and 15 are in correct location.
    Reset Grid for design.
    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
    [SparkFun_MicroMod_GNSS_Function_Board_ZED-F9P.brd, SparkFun_MicroMod_GNSS_Function_Board_ZED-F9P.sch]
2022-05-03 Unlocked all components for panelization.
    [SparkFun_MicroMod_GNSS_Function_Board_ZED-F9P.brd]
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2022-05-06 change due to mfgring issue.
    There was no TSTOP on ground pad of U7. Added TSTOP.
    [SparkFun_MicroMod_GNSS_Function_Board_ZED-F9P.brd, SparkFun_MicroMod_GNSS_Function_Board_ZED-F9P.sch]
2022-05-06 update to v02 for mfgr error.
    [SparkFun_MicroMod_GNSS_Function_Board_ZED-F9P.brd, SparkFun_MicroMod_GNSS_Function_Board_ZED-F9P.sch]
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2022-06-13 v03 protos update.
    Center and update flags.
    Fix RTK STAT circuit.
    Fix voltage divider for USB detect.
    Add I2C PURs.
    Add a PUR for the reset line outside isolation.
    Changed PWR LED resistor to 1k.
    Moved PPS and RTK LEDs to top of board.
    Removed RF_GND.
    Rerouted board.
    [SparkFun_MicroMod_GNSS_Function_Board_ZED-F9P.brd, SparkFun_MicroMod_GNSS_Function_Board_ZED-F9P.sch]
2022-06-13 Fixed note font.
    [SparkFun_MicroMod_GNSS_Function_Board_ZED-F9P.sch]
2022-06-14 Update post Reds review.
    Line up USB Shield JP with CC resistors.
    Relabel C8 with value, remove tolerance
    Remove cap placement note.
    Make USB Shield JP NC
    Rename JPs to their function
    Add USBSHLD Jumper text
    Acid Traps
    Label PPS header
    Add measures
    Align RST/EXTINT PTH in 0.1" grid
    Move C3 back a bit from VREG
    Move GND PTH back from C7
    Relabel GRF as GND in silk
    Recenter EXTINT AND RESET GND silk
    [SparkFun_MicroMod_GNSS_Function_Board_ZED-F9P.brd, SparkFun_MicroMod_GNSS_Function_Board_ZED-F9P.sch]
2022-06-14 Added measures on the right side.
    [SparkFun_MicroMod_GNSS_Function_Board_ZED-F9P.brd]
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2022-06-15 Retune LED brightness.
    Per experiment Pete performed.
    Red LED = 1kOhm @3.3V
    Blue LED = 4.7kOhm @3.3V
    Replaced Yellow LED with Blue LED to match design standards.
    [SparkFun_MicroMod_GNSS_Function_Board_ZED-F9P.brd, SparkFun_MicroMod_GNSS_Function_Board_ZED-F9P.sch]
2022-06-15 Add Reds Panel.
    Add panel for reds.
    [SparkFun_MicroMod_GNSS_Function_Board_ZED-F9P-Panel.GBL, SparkFun_MicroMod_GNSS_Function_Board_ZED-F9P-Panel.GBO, SparkFun_MicroMod_GNSS_Function_Board_ZED-F9P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]
2022-07-20 Decrease V_USB vdiv resistors.
    Decrease by 2 orders of magnitude to allow more current flow for V_DETECT.
    22k -> 220
    47k -> 470
    [SparkFun_MicroMod_GNSS_Function_Board_ZED-F9P.brd, SparkFun_MicroMod_GNSS_Function_Board_ZED-F9P.sch]

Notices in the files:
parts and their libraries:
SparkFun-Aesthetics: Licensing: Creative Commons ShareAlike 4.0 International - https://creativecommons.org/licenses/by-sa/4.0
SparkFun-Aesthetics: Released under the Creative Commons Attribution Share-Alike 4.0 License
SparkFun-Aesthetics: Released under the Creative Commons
